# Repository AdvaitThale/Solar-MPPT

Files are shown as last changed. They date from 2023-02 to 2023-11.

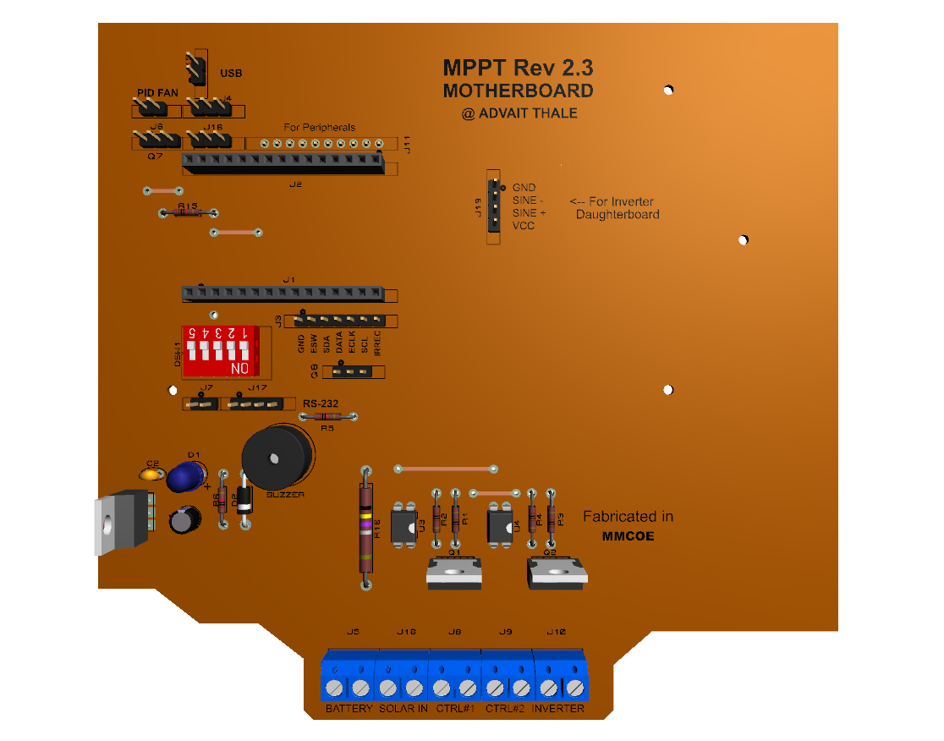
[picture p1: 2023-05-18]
Final Review/Top.PNG

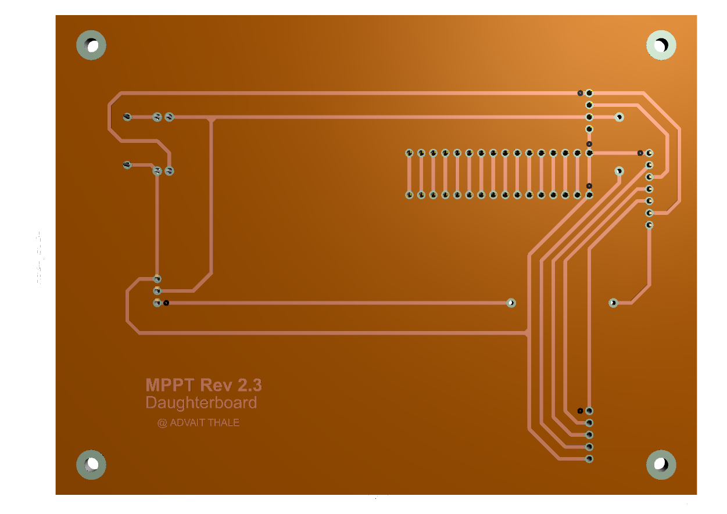
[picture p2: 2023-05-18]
Final Review/Back LCD.PNG

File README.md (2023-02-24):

# Solar-MPPT
***************************************************************
The basic functionality of the device is based on previous generation Solar MPPTs, but it is fully autonomous (alpha ver) using ESP32 as microcontroller.
The file named `MPPT_Port-Xtensa.ino` code is final port of MPPT on the ESP32. Also, `MPPT_Port-328P.ino` shows an overview of how MPPT will work with ATMega328P microcontroller (with reduced functionality).It is equipped with 20*4 Character LCD (for device & energy status), Function Buttons, ESP32 Microcontroller, Solar Inlet, 30A FUSE, Sleep Mode, Webserver, 2 x PT-100(for Indoor & Outdoor Temp.), RS-232 Interface(at 9600),Program Serial(at 115200), Internal DIP Switches (for system configuration), Relay driven Outputs(for automation purpose), I/O for interfacing external sensors and automation purpose. The live status is displayed on LCD, the Webserver(at 192.168.1.1) to freely receive updates on PC/smartphone as well as the data log can be viewed via both RS-232 (DB9) or USB A Serial ports. Refer README.md and attached datasheets for furthur details on MPPT.

 IR Remote Keypad Hex Map:
  
        +------------------+              
        |              DC  |
        |                  |
        |  92    93    CC  |
        |  8E    8F    C8  |
        |  8A    8B    C4  |
        |  CF    87    82  |
        |                  |
        |  80    9C    85  |
        |  81  8C  DD  86  |
        |                  |
        |        CA        |
        |  88 99 CE C1 C5  |
        |        D2        |
        |                  |
        |  DA          D6  |
        |      98  95      |
        |                  |
        |  CD    91    D0  |
        |  8D  97  C3  83  |
        |                  |
        |  89  84  D9  96  |
        |                  |
        |     hathw@y      |
        +------------------+

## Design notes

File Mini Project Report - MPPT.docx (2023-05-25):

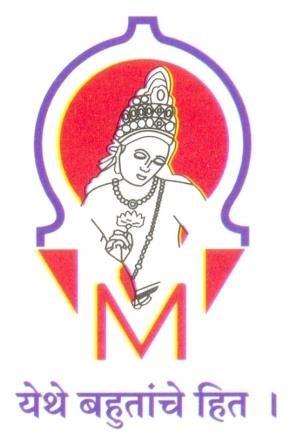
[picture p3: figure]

T.E. MINI PROJECT REPORT

On

“Maximum Power Point Tracker with Controllable Opto-isolated Solid-state outputs and function driven status display”

Submitted by

Advait Thale Exam No:-T190453143

Mansi Veer Exam No:-T190453148

UNDER THE GUIDANCE OF

Prof. Jitendra Bakliwal (Internal Guide)

IN PARTIAL FULFILLMENT OF

T.E. (ELECTRONICS & TELECOMMUNICATION) SAVITRIBAI PHULE PUNE UNIVERSITY

2022-2023

MARATHAWADA MITRA MANDAL’S COLLEGE OF ENGINEERING, PUNE- 52

DEPARTMENT OF ELECTRONICS AND TELECOMMUNICATION

MARATHAWADA MITRA MANDAL’S

COLLEGE OF ENGINEERING, PUNE

CERTIFICATE

This is to certify that the Mini Project Report entitled,

“Maximum Power Point Tracker with Controllable Opto-isolated Solid-state outputs and function driven status display”

Submitted by

Advait Thale Exam No:- T190453143

Mansi Veer Exam No:- T190453148

is Bonafide work carried out by them under the supervision of Prof. Mr. Jitendra Bakliwal and it is approved for the partial fulfilment of requirement of Savitribai Phule Pune University for award of the degree of Bachelor of Engineering (Electronics and Telecommunication).

This project report has not been earlier submitted to any other Institute or University for the award of any degree or diploma.

Mr. Jitendra Bakliwal Dr. G. S. Gawande Dr.V. N. Gohokar

Project Guide Head of Department Principal

Department of E&TC Department of E&TC MMCOE

Place: Pune

Date:

INDEX

Abstract

List of Figures

1. Chapter 1 07
  1.1 Introduction 08
2. Chapter 2 10
  2.1 Literature Survey 11
3. Chapter 3 13
  3.1 System Specifications 14
  3.2 Block Diagram 14
4. Chapter 4 16
  4.1 Hardware Implementation 17
  4.2 System Schematic and Circuit Diagram 19
  4.3 PCB Artwork 20

4.4 3D Render 21

1. Chapter 5 24
  1.1 Practical Implementation 25
2. Chapter 6 27
  2.1 Conclusion… 28
  2.2 Future Scope 28
  2.3 Schedule 26

REFERENCES

LIST OF FIGURES

Sr. No. | Name of Figure | | Page No.
3.1 | Block Diagram | | 14
4.1 | ESP32 Dev Module | | 17
4.2 4.3 | Circuit Diagram PCB Layout of Main Board | | 19 20
4.4 | PCB Layout of LCD Daughterboard | | 20
4.5 | Top View of Main Board | | 21
4.6 | Isometric View of Main Board | | 21
4.7 | Back View of Main Board (Routes) | | 22
4.8 | Front view of LCD Daughterboard (Routes) | | 23
4.9 | Back view of LCD Daughterboard (Routes) | | 23
5.1 | Parameters on LCD | | 25
5.2 | Practical Implementation | | 25
5.3 | Serial Monitor Output | | 26

ABSTRACT

The abstract focuses on controllable Maximum Power Point Tracking (MPPT) techniques designed to further enhance the power output of photovoltaic (PV) systems. As solar energy becomes increasingly prominent, optimizing the performance of PV modules through effective MPPT algorithms has become crucial. This abstract provides a concise overview of controllable MPPT techniques and their potential for maximizing PV power generation.

The aim was to display how much voltage is being generated by photovoltaic panels, current flowing through the batteries or battery bank, temperature of battery bank along with cut-off protection in case of battery overheating, customizable charging, settings menu which will be displayed on character LCD and controlled by KY-040 rotary encoder module and most importantly controlled DC outputs.

ORGANISATION OF REPORT

The project “Maximum Power Point Tracker with Controllable Opto-isolated Solid-state outputs and function driven status display” is thoroughly explained in all the chapters in this report. Planning and organization of this subject has been done with curiosity and as per the given deadline. So, this project gives the entire overview of this subject.

The report is divided into various chapters to understand each aspect of the subject technically and separately.

Chapter 1:

Gives a brief introduction of this project. This consists of the introduction and scope of the project, objective of this project.

Chapter 2:

Gives brief review of the related Literature and present scenario of proposed system.

Chapter 3:

Describes System Schematic & Specification and block diagram with its detailed explanation.

Chapter 4:

Describes the implementation of the project with its hardware and software description that is detailed analysis of each component.

Chapter 5:

Describes the implementation of small modules and algorithms used in projects. Shows the results and observations.

Chapter 6:

Describes Semester wise planning and management.

CHAPTER 1

INTRODUCTION

1.1 INTRODUCTION:

The integration of maximum power print tracking (MPPT) techniques with controllable opto-isolated solid-state outputs presents a promising solution for enhancing the efficiency and performance of power conversion systems and also represents a compelling research area that holds significant potential for enhancing the efficiency, reliability and safety of power conversion systems in various applications. This project aims to explore the advancements in this area and provide an overview of the current state of the art research and aims to explore the synergistic effects of combining MPPT algorithms, quasi-resonant topologies, and hardware-controlled opto-isolated AC outputs, with a particular focus on their impact on system performance and functionality.

MPPT algorithms plays a crucial role in photovoltaic (PV) systems by dynamically adjusting the operating point of solar panels to extract the maximum power under varying environmental conditions. The integration of MPPT techniques with quasi-resonant topologies offers an opportunity to mitigate switching losses and optimize power transfer, thereby improving the overall efficiency of power conversion systems. Quasi-resonant topologies, characterized by resonant components operating near their natural frequencies, facilitate soft switching and reduce stress on power devices, contributing to enhanced performance and reduced power losses.

Furthermore, a function-driven status display adds value by providing real-time feedback on system performance, fault detection, and diagnostic information. The display acts as a user-friendly interface, allowing operators to monitor the system's operation, identify potential issues, and perform necessary maintenance promptly. This feature facilitates efficient system management, improves reliability, and streamlines troubleshooting processes. This project aims to delve deeply into the theoretical and practical aspects of integrating MPPT techniques, quasi-resonant topologies, and hardware-controlled opto-isolated AC outputs. Through experimental investigations and analysis, the project will evaluate the performance metrics, such as power efficiency, response time, and power quality, to assess the advantages and challenges of this integrated approach. Furthermore, the project will explore control strategies, optimization techniques, and design considerations to maximize the benefits of this integrated system.

The outcomes of this project will contribute to the existing body of knowledge in the field of power electronics, renewable energy, and system integration. The findings will shed light on the feasibility, advantages, and potential applications of combining MPPT techniques, quasi-resonant topologies, and hardware-controlled opto-isolated AC outputs. This knowledge will provide valuable insights for researchers, engineers, and practitioners seeking to optimize power conversion systems, improve renewable energy utilization, and enhance the safety and reliability of electrical systems.

CHAPTER 2

LITERATURE SURVEY

2.1 LITERATURE SURVEY:

As part of pre-study, an elaborate literature survey was conducted. The literature survey presents an overview on the Maximum Power Point Tracker, Controllable Opto-isolated Solid-state outputs, and function scrolling on LCD. The journals were analysed, and content was presented. After analysing what systems have been published in the journals, ideas which were presented focused on improving the existing system and trying to implement a cost-efficient alternative to existing MPPTs [4].

After thoroughly classifying every MPPTs available in the market offline as well as online, there exists no display to properly check how much voltage is being generated by photovoltaic panels, current flowing through the batteries or battery bank, temperature of battery bank along with cut-off protection in case of battery overheating [4], customizable charging, and most importantly controlled DC outputs.

With the help of newly designed IoT based microcontrollers [6], the goal of adding above requirements atop of normal MPPT operation improving visibility of work being done were achieved. It has emerged as a useful industrial tool for about 25 years and is growing at a higher speed. The applications of newly designed microcontrollers in industries as well as in commercial areas have been typically seen in wireless monitoring, wireless load controlling, various types of automation systems including domestic version as home automation system, remote quality control, remote object sorting, and remote robotic operation and guidance. It has become a yielding tool in product inspection and analysis because it reduces cost, effort, and time with a significant level of accuracy and reliability. With the recent advancement in technology, IoT based microcontrollers can be applied to remotely control as well as monitor various environmental parameters and to collect data from different sensors connected, etc. The application of IoT based microcontrollers has been seen in domestic, medical, industrial, security fields, and in remote monitoring.

The ESP32 microcontroller for controlling and monitoring all the ongoing operations was used [8]. Also, C, C++ programming languages were the preferred choices as the whole ESP program environment is built on them and they are the most efficient programming languages till date for writing libraries and to efficiently compile the program. ESP32 is low cost, SoC single board 32-bit microcontroller with built-in 2.4 GHz Wi-Fi Radio, Bluetooth 4.2 and Bluetooth Low Energy [7]. It can be used to store and display web pages on the PC or smartphone in the browser and the data from the sensors can be viewed in real time. A 16x2 character LCD placed atop the enclosure is used to display the voltage, current and temperature parameters of the battery and produced voltage from PV panels [1] [4].

CHAPTER 3

SYSTEM SCHEMATIC &

SPECIFICATION

3.1 SPECIFICATIONS:

1. 12-24V Photovoltaic Panel Input
2. MOSFET Controlled Output x 2
3. Outputs Controlled by IR Remote
4. Character LCD for Power Status
5. Webserver Access at 192.168.1.1
6. 12V Lead Acid Battery (4V 1AH x 3 in series)
7. Overtemperature Battery Cut-off Protection
8. Port for KY-040 Rotary Encoder for Settings Menu
9. System Alarms through integrated beeper

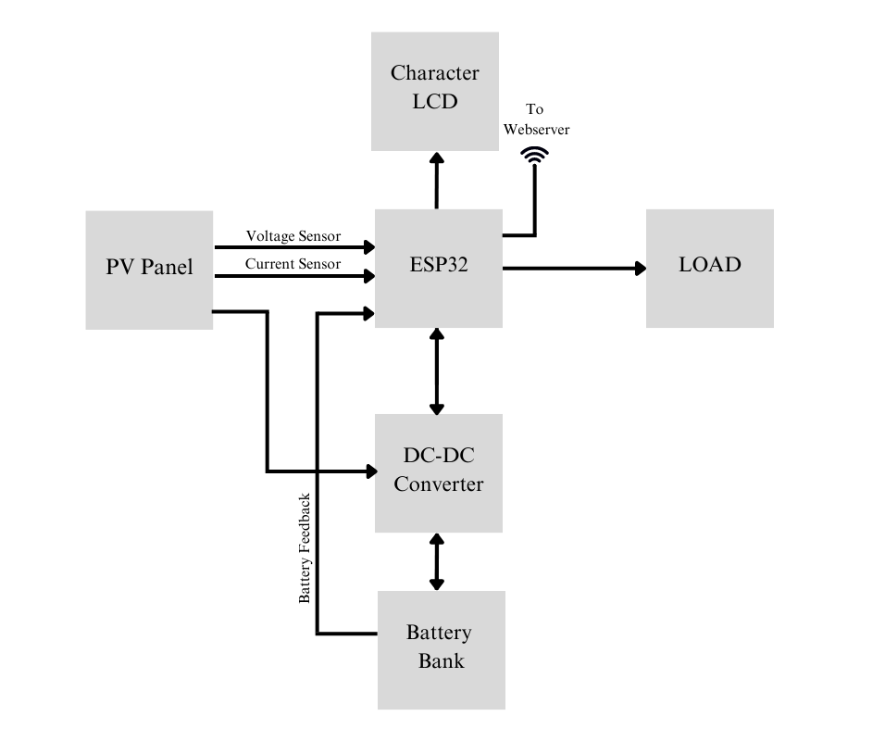
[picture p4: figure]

3.2 BLOCK DIAGRAM:

Fig. 3.1: Block Diagram of ESP32 Based MPPT with Status LCD

WORKING:

The ESP32 is used to control all the important tasks for charging/ using battery bank, to monitor the voltage and current of battery and power generated by PV Panels. The obtained data can be viewed on the character LCD atop of the MPPT enclosure as well as on the webserver in real time. With the help of connected current sensor and ADC, it constantly checks how much voltage is being generated by photovoltaic panels, current flowing through the batteries or battery bank, temperature of battery bank along with cut-off protection in case of battery overheating. The two MOSFET controlled outputs can be used for connecting DC load of 12V Max. The outputs are normally controlled by microcontroller at normal MPPT operations but can be manually controlled by IR remote. If the battery is overheated or is fully charged in those intervals various alerts occur. A header port for KY040 rotary encoder is kept for controlling the output load voltage and battery charge parameters. Also, a header for inverter is routed on the PCB for Inverter daughterboard for further expansion.

CHAPTER 4

CIRCUIT DESIGN &

PCB ARTWORK

4.1 HARWARE USED:

- ESP32:

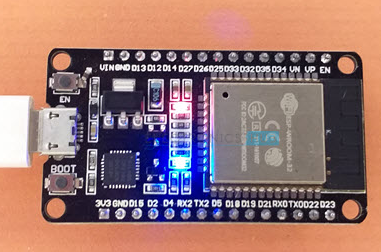
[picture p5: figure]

Fig. 4.1: ESP32 Dev Module

An ESP32 is a popular and versatile microcontroller and Wi-Fi/Bluetooth module that is widely used for IOT applications. The ESP32 is powered by a dual core Tensilica Xtensa LX6 microprocessor. Each core operates at a clock frequency of up to 240 MHz. The ESP32 has a significant number of GPIO pins available for connecting external components and sensors. It typically comes with 4MB to 16MB of built-in flash memory for storing firmware and programs. The power consumption of the ESP32 can vary depending on the usage and operating conditions [7]. It offers low-power modes and features to optimize energy efficiency.

- LM7805:

The LM7805 is a popular linear voltage regulator IC that provides a fixed output voltage of +5 V. It is widely used in electronic circuits to regulate and provide a stable +5V power supply. The LM7805 requires an input voltage higher than the desired output voltage [3]. It typically operates within a range of 7V to 35V. The LM7805 provides a fixed output voltage of +5V. The dropout voltage is the minimum voltage required between the input and output terminals for the LM7805 to regulate the output voltage properly.

- 116*2 Character LCD:

A 16*2 LCD (Liquid Crystal Display) is a commonly used alphanumeric display module that can display 16 characters in each of its rows. It is widely used in various electronic projects and devices for displaying information. The 16*2 LCD module is usually based on an HD44789 or compatible controller. This controller handles the interfacing between the microcontroller and the LCD module, providing commands and data for display control. The 16*2 LCD module is usually interfaced with a backlight pin. The most common interface is the 4-bit or 8-bit parallel interface, where data and control signals are sent to the LCD using multiple data lines.

- 4V Lead Acid Battery:

A 4V lead-acid battery is a type of rechargeable battery commonly used in various applications, including automotive, solar power systems, uninterruptible power supplies (UPS) and other backup power applications. The 4V lead-acid battery is based on a lead-acid chemistry, which consists of lead plates and an electrolyte solution of sulfuric acid (H2SO4). The recommended operating temperature range for lead-acid batteries is typically between -20 °C to 50 °C. Extreme temperatures outside this range can affect the battery’s performance and overall lifespan [2].

- 2N2222A:

The 2N2222A is a popular NPN bipolar junctions’ transistor (BJT) commonly used in a wide range of electronic circuits for switching and amplification purposes. The 2N2222A is an NPN (Negative-Positive-Negative) bipolar junction transistor, which means it consists of three layers of semiconductor material: the emitter(N) , base (P) and collector (N). It is designed to control current flow between the collector and emitter terminals using a voltage applied to the base terminal.

- IRFZ44:

The IRFZ44 is a popular power MOSFET (Metal-Oxide-Semiconductor Field-Effect Transistor) used for high-power switching applications. It is commonly employed in a variety of electronic circuits, such as motor control, LED lighting, and power supplies. The IRFZ44 is an N-channel MOSFET, meaning it is designed to control the flow of current between the drain and source terminals using a voltage applied to the gate terminal. The IRFZ44 is commonly available in a TO-220 package, which allows for easy mounting and heat dissipation.

- IR Receiver (VS1838B):

An IR (Infrared receiver) is a component used to detect and receive infrared signals from remote controls, IR transmitters or other IR sources. It is commonly used in applications such as remote-control systems, home automation and infrared communication. IR receivers typically use a photodiode or phototransistor as the detecting element. These components are sensitive to infrared signals within a specific wavelength range.

4.2 System Schematic and Circuit Diagram:

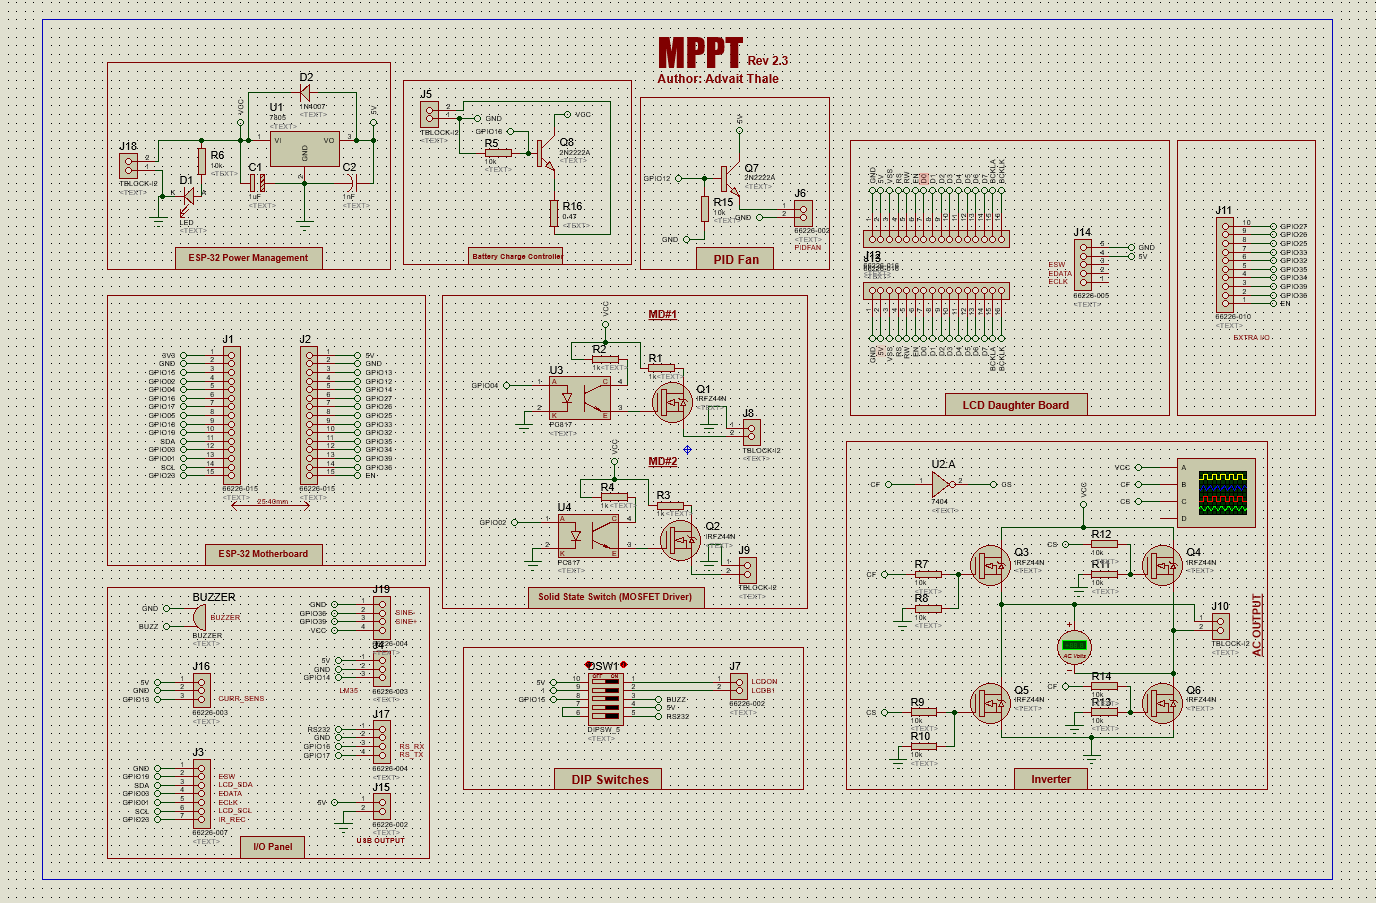
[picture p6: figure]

Fig. 4.2: Circuit Diagram

4.3 PCB Artwork:

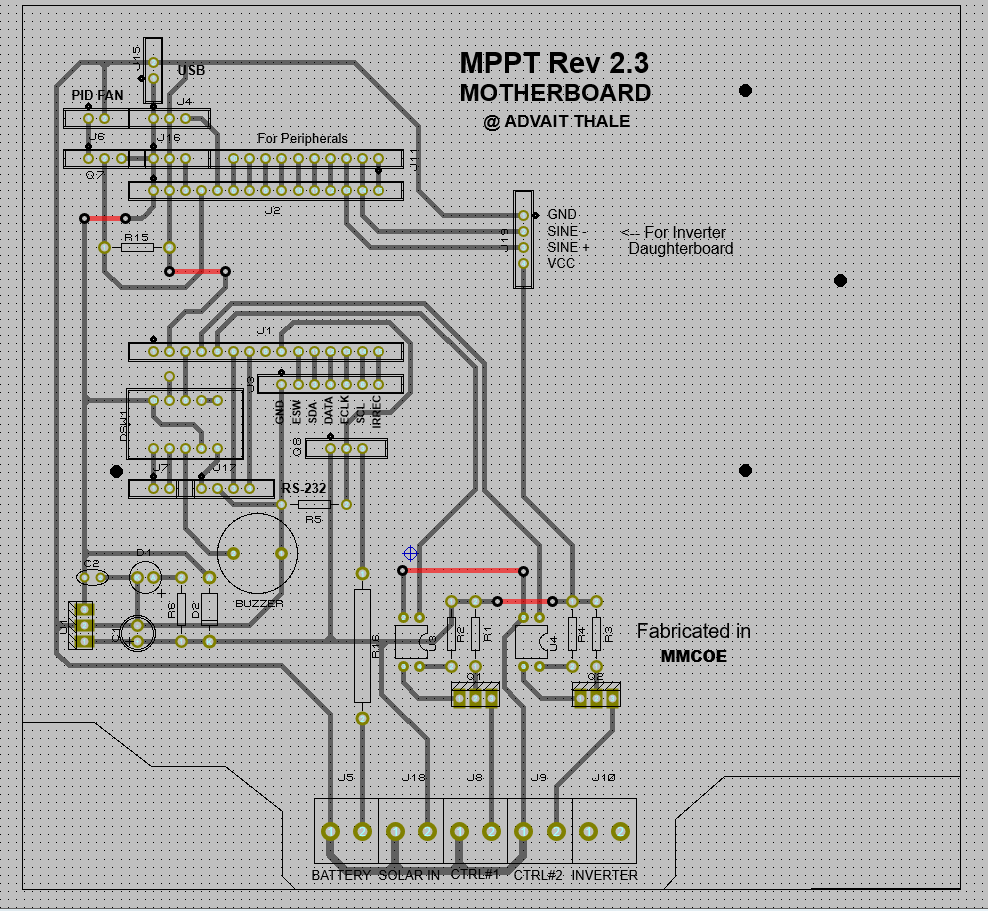
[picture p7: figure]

Fig. 4.3: PCB Layout of Main Board

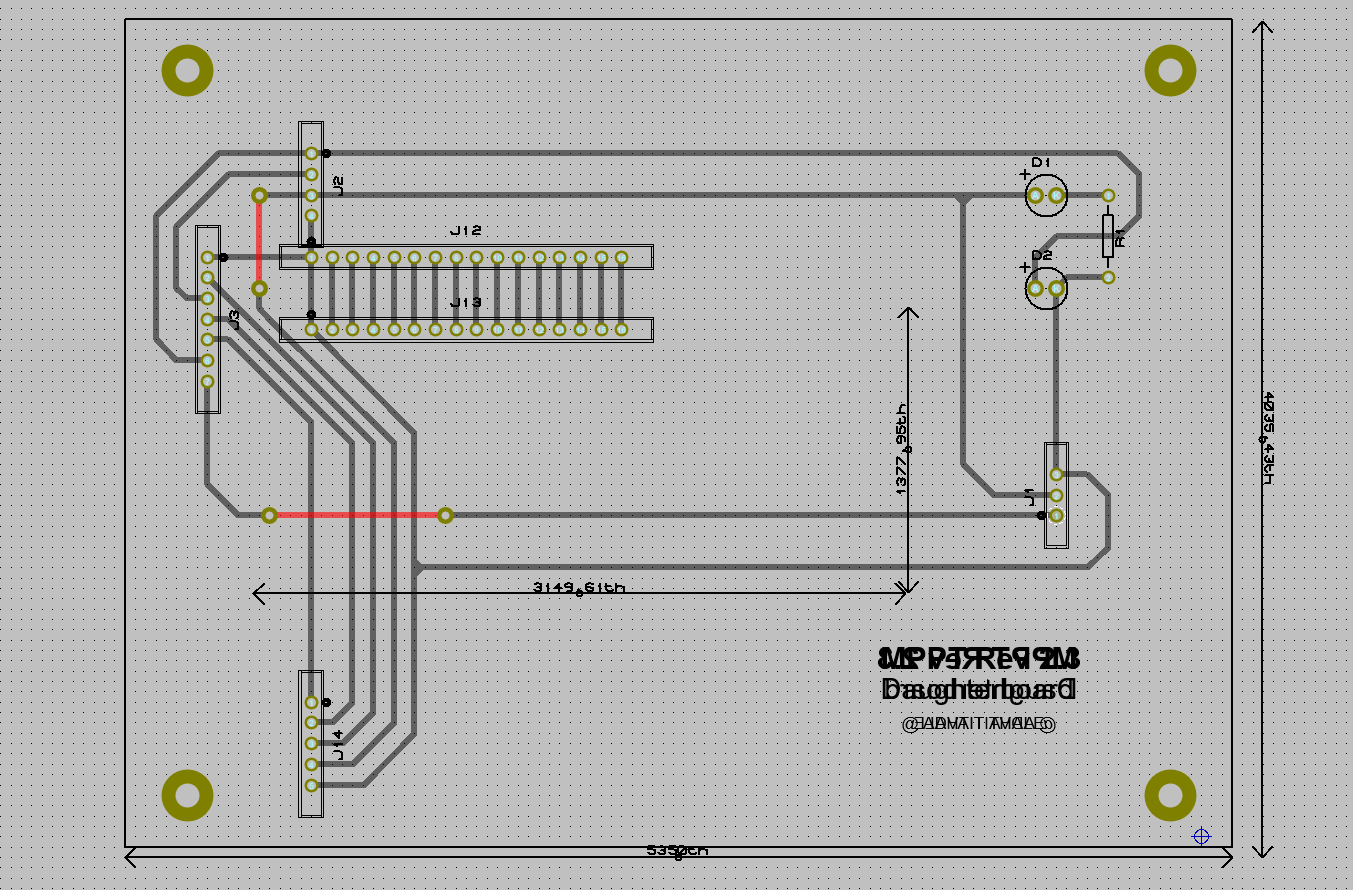
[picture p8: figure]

Fig. 4.4: PCB Layout of LCD Daughterboard

4.4 3D Render of PCB:


Fig. 4.5: Top View of Main Board

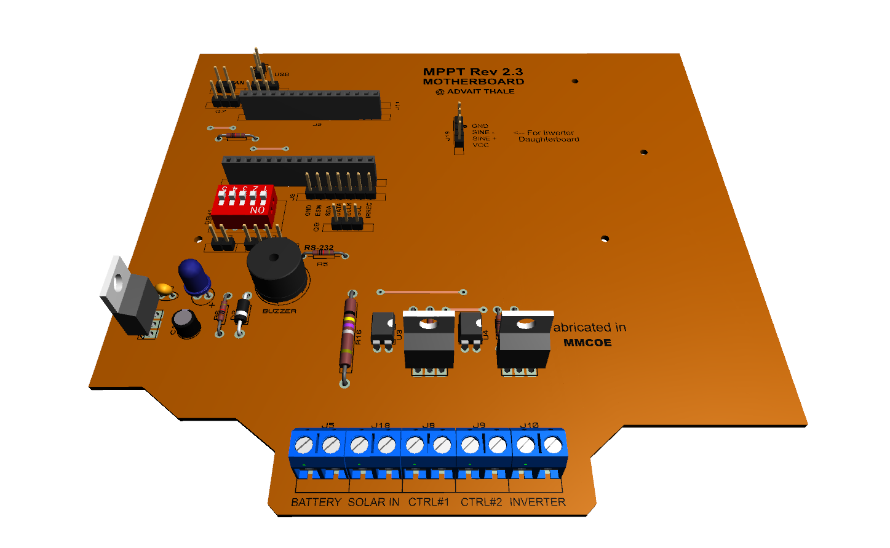
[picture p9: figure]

Fig. 4.6: Isometric view of Main Board

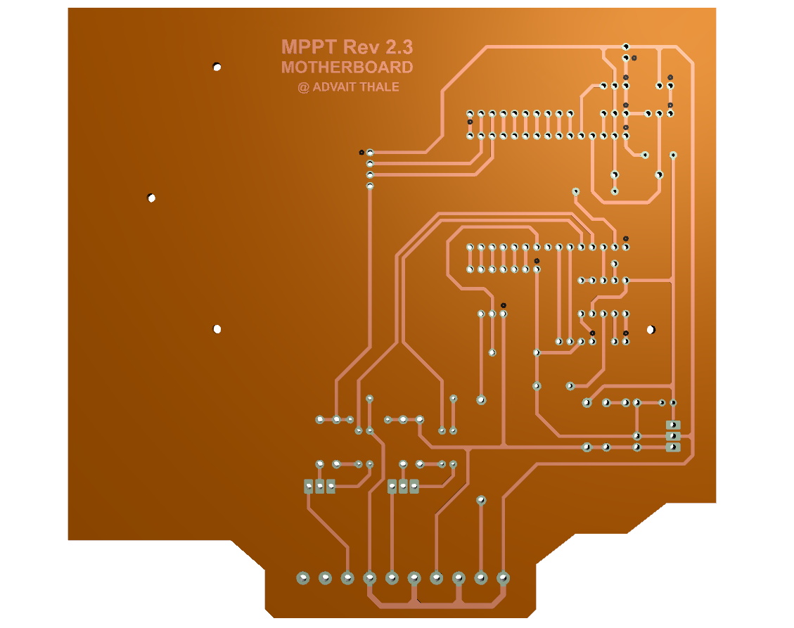
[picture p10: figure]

Fig. 4.7: Back view of Main Board (Routes)

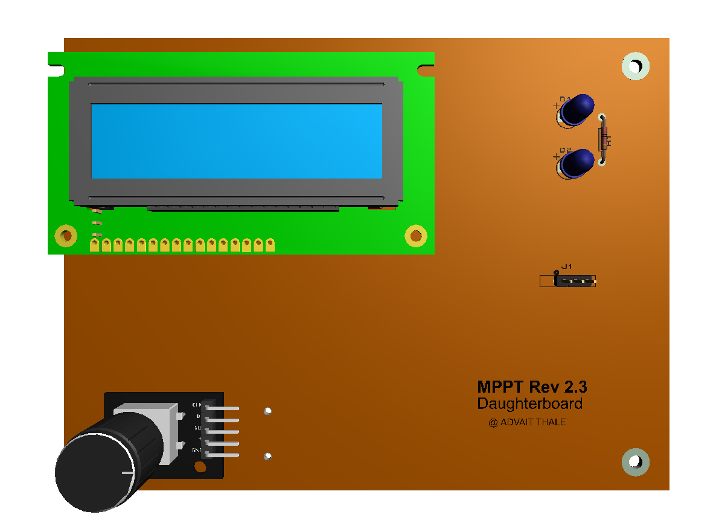
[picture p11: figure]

Fig. 4.8: Front view of LCD Daughterboard (Routes)


Fig. 4.9: Back view of LCD Daughterboard (Routes)

CHAPTER 5

HARDWARE IMPLEMENTATION

5.1 HARDWARE IMPLEMENTATION:

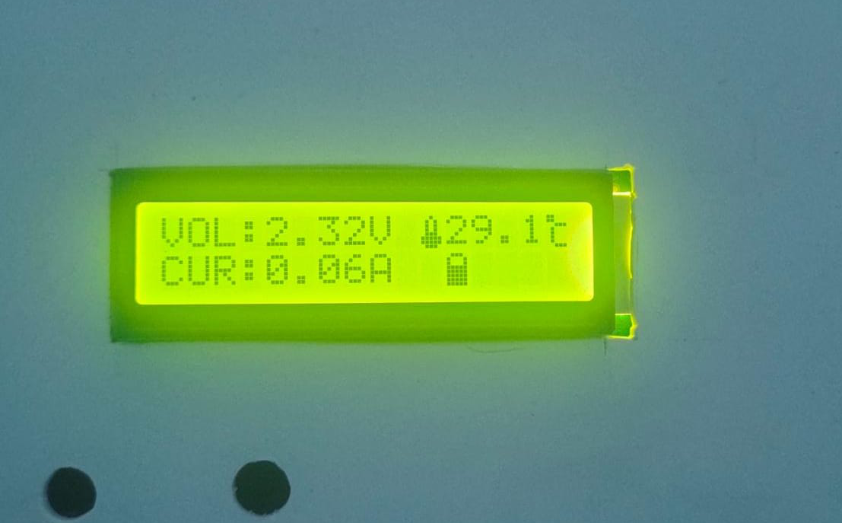
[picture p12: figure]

Fig. 5.1: Parameters on LCD

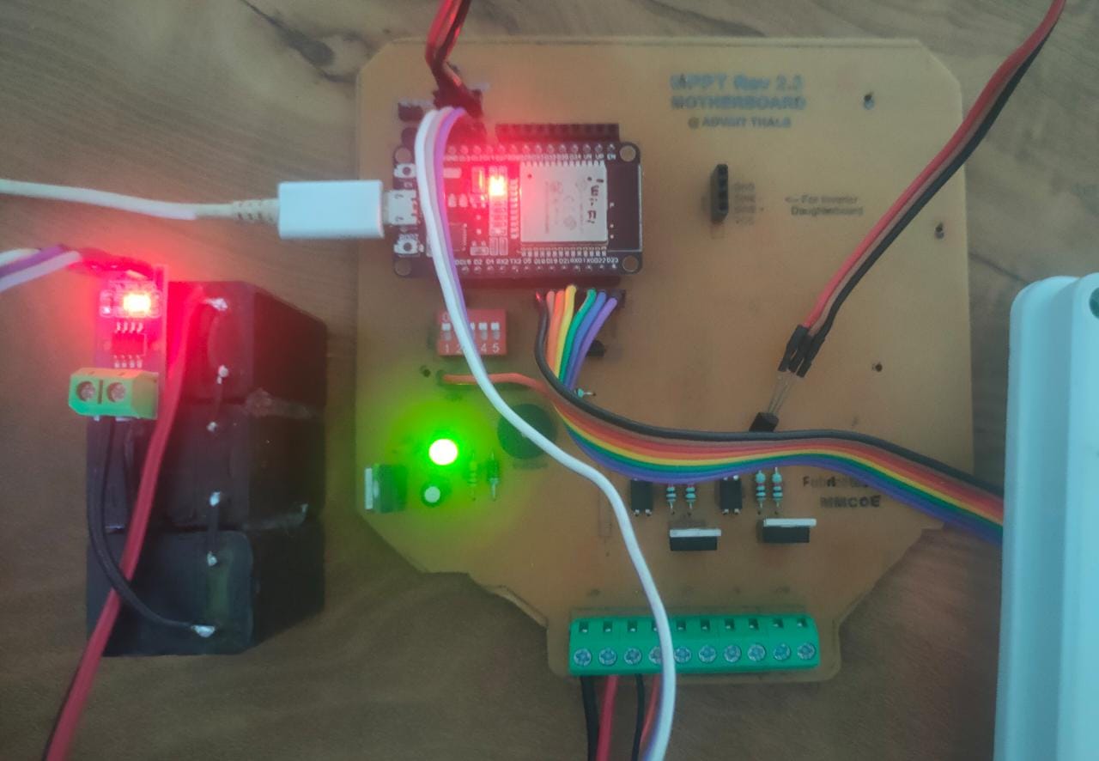
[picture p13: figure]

Fig. 5.2: Practical Implementation

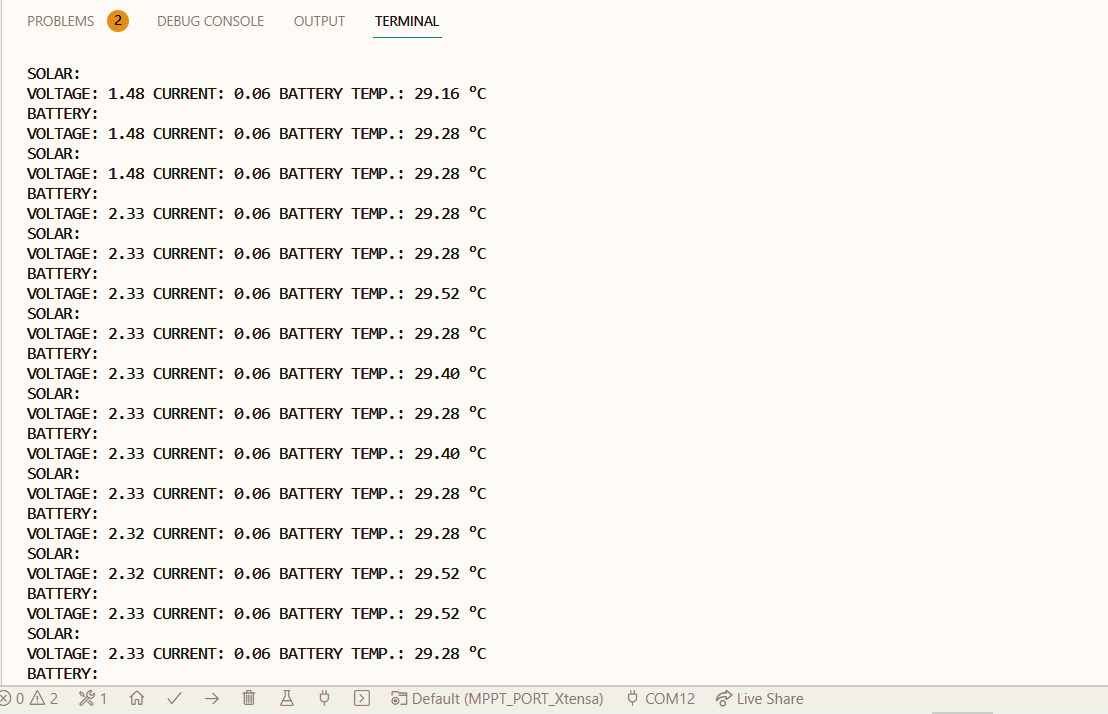
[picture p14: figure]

Fig. 5.3: Serial Monitor Output

CHAPTER 6

PROJECT PLANNING &

METHODOLOGY

6.1 CONCLUSION:

Thus, a working prototype of Output controllable MPPT with Webserver was demonstrated. It shows the Battery charging parameters such as voltage, current across and input power parameters on the character LCD as well as can be viewed on the Webserver by connecting to ESP32 via Wi-Fi and browsing 192.168.1.1 address on the internet browser such as Chrome, Edge, etc. The goal was to try and improve productivity and efficiency of already available device in the market and concluded that it is doable. The data obtained provides high accuracy, good repeatability and increases productivity.

6.2 FUTURE SCOPE:

Future work that can be implemented in this project is, an inverter daughterboard to produce AC output directly from the MPPT with provided connector on PCB can be attached, thereby increasing productivity of device. It can be upgraded to work on higher voltages by simply changing software and hardware components and parameters, respectively. It can be implemented in domestic as well as commercial areas with few advancements better meet overall power demands.

6.3 SCHEDULE:

Week 1 (28-01-23): Group formation and problem statement search.

Week 2 (03-02-23): Project topic finalization.

Week 3 (10-02-23): Problem solving and circuit designing.

Week 4 (17-02-23): Component availability check according to circuits.

Week 5 (24-02-23): Finalizing circuit diagram with available components.

Week 6 (03-03-23): PCB Designing.

Week 7 (10-03-23): Purchased Enclosure and adjusted PCB size.

Week 8 (17-03-23): Finalizing PCB Artwork.

Week 9 (24-03-24): Manufacturing PCB.

Week 10 (31-03-23): Assembling components on PCB and Testing.

Week 11 (08-04-23): Optimizing code and LCD Daughterboard design.

Week 12 (13-04-23): Code correction and testing.

Week 13 (21-04-23): Final PCB fitting in enclosure and project review.

Week 14 (28-04-23): Project Presentation.

REFERENCES:

[1] Paul Horowitz, Winfield Hill, “Solar Cells”, in The Art of Electronics, Second Edition, Pg. 932-933.

[2] W. H. Hayt, J. E. Kemmerly, S. M. Durbin, “Ohm’s Law: Power Absorption”, in Engineering Circuit Analysis, Seventh Edition, Pg. 21-27

[3] Paul Horowitz, Winfield Hill, “Voltage, Current & Resistance”, in The Art of Electronics, Second Edition, Pg. 2-9.

[4] D. P. Kothari, I.J. Nagrath, “Solar Energy & its Utilisation”, in Modern Power System Analysis, Fourth Edition, Pg. 32-42

[5] Paul Horowitz, Winfield Hill, “Power Sources: Battery Types”, in The Art of Electronics, Second Edition, Pg. 920-931.

[6] Clint Smith, Daniel Collins, “Long Term Evolution: RF Coverage Analysis”, in Wireless Networks, Third Edition, Pg. 497-50

[7] Louis E. Frenzel, “Radio Frequency Wave Propagation”, in Communication Electronics, Third Edition, Pg. 247-251

[8] Clint Smith, Daniel Collins, “Long Term Evolution: Radio Spectrum”, in Wireless Networks, Third Edition, Pg. 211-213

[9] Paul Horowitz, Winfield Hill, “Measurement Transducers: Temperature”, in The Art of Electronics, Second Edition, Pg. 988-996.

MMCOE - B. E. ELECTRONICS AND TELECOMMUNICATION

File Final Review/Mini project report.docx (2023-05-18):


T.E. MINI PROJECT REPORT

## On

“Maximum Power Point Tracker with Controllable Opto-isolated Solid state outputs and function driven status display”

Submitted by,

Advait Thale (T190453143) Mansi Veer (T190453148)

UNDER THE GUIDANCE OF

Prof. Jitendra Bakliwal (Internal Guide)

IN PARTIAL FULFILLMENT OF

T.E. (ELECTRONICS & TELECOMMUNICATION) SAVITRIBAI PHULE PUNE UNIVERSITY

2021-2022

MARATHAWADA MITRA MANDAL’S COLLEGE OF ENGINEERING, PUNE- 52

DEPARTMENT OF ELECTRONICS AND TELECOMMUNICATION

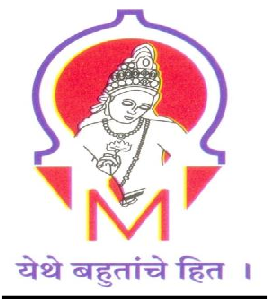
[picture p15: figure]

MARATHAWADA MITRA MANDAL’S

COLLEGE OF ENGINEERING, PUNE

CERTIFICATE

This is to certify that the Mini Project report entitled

“Maximum Power Point Tracker with Controllable Opto-isolated Solid state outputs and function driven status display”

Submitted by

Advait Thale Exam No:-T190453143

Mansi Veer Exam No:-T190453148

is bonafide work carried out by them under the supervision of Prof Mr.Jitendra Bakliwal and it is approved for the partial fulfillment of requirement of Savitribai Phule Pune University for award of the degree of Bachelor of Engineering (Electronics and Telecommunication).

This seminar report has not been earlier submitted to any other Institute or University for the award of any degree or diploma.

Dr. Jitendra Bakliwal

Project Guide

Department of E&TC

Dr. G. S. Gawande

Head of Department Department of E&TC

Dr. V. N. Gohokar Principal

Place: Pune Date:

## INDEX

1. Chapter1 06
  1.1 Introduction 07
2. Chapter 2 09
  2.1 Literature Survey 10
3. Chapter3… 11
  3.1 System schematic and specification 12
  3.2 Block diagram 13
4. Chapter 4 14
  4.1 Hardware Implementation with PCB Artwork 15
  4.2 3D Render… 17
5. Chapter 5 18
  5.1 algorithm 19
  5.2 Implementation of sorting mechanism 20
  5.3 21
6. Chapter 6 24
  6.1 Conclusion… 25
  6.2 Future Scope 25

## LIST OF FIGURES

Sr. No. | Name of Figure | Page No.
3.1 | Block Diagram
4.1 | Raspberry-pi module
4.2 | Schematic Screenshot of PCB Routes
5.1 | Flow Chart
5.2 | Controller
5.3 | Screenshot of Program and Serial Monitor
5.4 | Practical Working Image
5.5 | Commands required for capturing an image
5.6(a) | Top view of PCB (3D)
5.6(b) | Isometric view of PCB (3D)
5.6(c) | Back view of PCB (Routes) (3D)

# ABSTRACT

# ORGANISATION OF REPORT

Our project “Maximum Power Point Tracker with Controllable Opto-isolated Solid state outputs and function driven status display” is thoroughly explained in all the chapters in this report . Planning and organization of this subject has been done with curiosity and as per the given deadline. So this project gives the entire overview of this subject.

The report is divided into various chapters to understand each aspect of the subject technically and separately.

## Chapter 1:

## Gives a brief introduction of this project. This consists of the introduction and scope of the project, objective of this project.

## Chapter 2:

## Gives brief review of the related Literature and present scenario of proposed system.

## Chapter 3:

## Describes System Schematic & Specification and block diagram with its detailed explanation.

## Chapter 4:

## Describes the implementation of the project with its hardware and software description that is detailed analysis of each component.

## Chapter 5:

## Describes the implementation of small modules and algorithms used in projects. Shows the results and observations.

## Chapter 6:

## Describes Semester wise planning and management.

# CHAPTER 1 INTRODUCTION

## 1.1 INTRODUCTION

The integration of maximum power print tracking (MPPT) techniques with controllable opto-isolated solid state outputs presents a promising solution for enhancing the efficiency and performance of power conversion systems and also represents a compelling research area that holds significant potential for enhancing the efficiency , reliability and safety of power conversion systems in various applications. This project aims to explore the advancements in this area and provide an overview of the current state of the art research and also aims to explore the synergistic effects of combining MPPT algorithms, quasi-resonant topologies and hardware-controlled opto-isolated AC outputs,with a particular focus on their impact on system performance and functionality.

MPPT algorithms plays a crucial role in photovoltaic (PV) systems by dynamically adjusting the operating point of solar panels to extract the maximum power under varying environmental conditions.The integration of MPPT techniques with quasi-resonant topologies offers an opportunity to mitigate switching losses and optimize power transfer, thereby improving the overall efficiency of power conversion systems. Quasi-resonant topologies, characterized by resonant components operating near their natural frequencies, facilitate soft switching and reduce stress on power devices, contributing to enhanced performance and reduced power losses.

Furthermore, a function-driven status display adds value by providing real-time feedback on system performance, fault detection, and diagnostic information. The display acts as a user-friendly interface, allowing operators to monitor the system's operation, identify potential issues, and perform necessary maintenance promptly. This feature facilitates efficient system management, improves reliability, and streamlines troubleshooting processes.This project aims to delve deeply into the theoretical and practical aspects of integrating MPPT techniques, quasi-resonant topologies, and hardware-controlled opto-isolated AC outputs. Through experimental investigations and analysis, the project will

evaluate the performance metrics, such as power efficiency, response time, and power quality, to assess the advantages and challenges of this integrated approach. Furthermore, the project will explore control strategies, optimization techniques, and design considerations to maximize the benefits of this integrated system.

The outcomes of this project will contribute to the existing body of knowledge in the field of power electronics, renewable energy, and system integration. The findings will shed light on the feasibility, advantages, and potential applications of combining MPPT techniques, quasi-resonant topologies, and hardware-controlled opto-isolated AC outputs. This knowledge will provide valuable insights for researchers, engineers, and practitioners seeking to optimize power conversion systems, improve renewable energy utilization, and enhance the safety and reliability of electrical systems.

## 2.1 LITERATURE SURVEY

As part of our pre-study, we conducted an elaborate literature survey. The literature survey presents an overview on the Maximum Power Point Tracker, Controllable Opto-isolated Solid state outputs, and function scrolling on LCD. The journals were analyzed and content was presented. After analyzing what systems have been published in the journals, we presented our ideas which were focussed on improving the existing system and trying to implement a cost efficient alternative to existing MPPTs.

After thoroughly classifying every MPPTs available in the market offline as well as online, we came to realize that, there exist no display to properly check how much voltage is being generated by photovoltaic panels, current flowing through the batteries or battery bank, temperature of battery bank along with cutoff protection in case of battery overheating, customizable charging and most importantly controlled DC outputs.

With the help of newly designed IoT based microcontrollers we can achieve the goal of adding above requirements atop of normal MPPT operation improving visibility of work being done. It has emerged as a useful industrial tool for about 25 years and is growing at a higher speed. The applications of newly designed microcontrollers in industries as well as in commercial areas have been typically seen in wireless monitoring, wireless load controlling, various types of automation systems including domestic version as home automation system, remote quality control, remote object sorting, and remote robotic operation and guidance. It has become a yielding tool in product inspection and analysis, because it reduces cost, effort, and time with a significant level of accuracy and reliability. With the recent advancement in technology, IoT based microcontrollers can be applied to remotely control as well as monitor various environmental parameters and to collect data from different sensors connected, etc. The application of IoT based microcontrollers has been seen in domestic, medical, industrial, security fields, and in remote monitoring.

We used ESP32 microcontroller for controlling and monitoring all the ongoing operations. We used C, C++ programming languages as the whole ESP program environment is built on them and they are the most efficient programming languages till date for writing libraries and to efficiently compile the program. ESP32 is low cost, SoC single board 32-bit microcontroller with built-in 2.4 GHz WiFi Radio, Bluetooth 4.2 and Bluetooth Low Energy. It can be used to store and display web pages on the PC or smartphone in the browser and the data from the sensors can be viewed in real time. A 16x2 character LCD placed atop the enclosure is used to display the voltage, current and temperature parameters of the battery and produced voltage from PV panels.

settings menu on the display voltage control.

# CHAPTER 3

SYSTEM SCHEMATIC AND SPECIFICATION

## 3.1 SPECIFICATION

## 3.2 BLOCK DIAGRAM

SOAR POWER

CONTROLLER

CONVEYOR AND SENSORS

RASPBERRYPI

CAMERA

DISPLAY

Fig 3.1 Block Diagram

DETAILED EXPLANATION:

The detailed block diagram of proposed system is shown in fig above.

    - The Camera is used for image acquisition.
    - Image acquired is given to RaspberryPi and OpenCV is used as an image processing platform. The OpenCV code written in Python is trained to examine the parameters like Shape, Colour and Texture for identification of products.
    - The RaspberryPi will generate the corresponding signals according to the image data interpreted by OpenCV. These signals are then given to the Controller which further handles the Sorting mechanism.
    - The controller will also perform the operation of counting the number of products and displaying the appropriate count on LCD.

# CHAPTER 4

SYSTEM DESIGN HARDWARE

AND SOFTWARE

## 4.1 HARDWARE IMPLEMENTATION AND PCB LAYOUT

- ESP32:

An ESP32 is a popular and versatile microcontroller and Wi-Fi/Bluetooth module that is wisely used for IOT applications. The ESP32 is powered by a dual+core Tensilica Xtensa LX6 microprocessor. Each core operates at a clock frequency of up to 240 MHz.The ESP32 has a significant number of GPIO pins available for connecting external components and sensors.It typically comes with 4MB to 16MB of built-in flash memory for storing firmware and programs.

The power consumption of the ESP32 can vary depending on the usage and operating conditions. It offers low-power modes and features to optimize energy efficiency.

- LM7805:

The LM7805 is a popular linear voltage regulator IC that provides a fixed output voltage of +5 V. It is widely used in electronic circuits to regulate and provide a stable +5V power supply. The LM7805 requires an input voltage higher than the desired output voltage. It typically operates within a range of 7V to 35V. The LM7805 provides a fixed output voltage of +5V. The dropout voltage is the minimum voltage required between the input and output terminals for the LM7805 to regulate the output voltage properly.

- 116*2 LCD:

A 16*2 LCD (Liquid Crystal Display) is a commonly used alphanumeric display module that can display 16 characters in each of its rows. It is widely used in various electronic projects and devices for displaying information. The 16*2 LCD module is usually based on an HD44789 or compatible controller. This controller handles the interfacing between the microcontroller and the LCD module , providing commands and data for display control. The 16*2 LCD module is usually interfaced with a backlight pin. The most common interface is the 4-bit or 8-bit parallel interface, where data and control signals are sent to the LCD using multiple data lines.

- 4V Lead Acid Battery:

A 4V lead-acid battery is a type of rechargeable battery commonly used in various applications, including automotive, solar power systems, uninterruptible power supplies (UPS) and other backup power applications. The 4V lead-acid battery is based on a lead-acid chemistry, which consists of lead plates and an electrolyte solution of sulfuric acid (H2SO4).The recommended operating temperature range for lead-acid batteries is typically between -20 degC to 50 degC. Extreme temperatures outside this range can affect the battery’s performance and overall lifespan.

- 2N2222A:

The 2N2222A is a popular NPN bipolar junctions transistor(BJT) commonly used in a wide range of electronic circuits for switching and amplification purposes.The 2N2222A is an NPN (Negative-Positive-Negative) bipolar junction transistor, which means it consists of three layers of semiconductor material:the emitter(N) , base (P) and collector (N). It is designed to control current flow between the collector and emitter terminals using a voltage applied to the base terminal.

- IRFZ44:

The IRFZ44 is a popular power MOSFET (Metal-Oxide-Semiconductor Field-Effect Transistor) used for high-power switching applications. It is commonly employed in a variety of electronic circuits, such as motor control, LED lighting, and power supplies. The IRFZ44 is an N-channel MOSFET, meaning it is designed to control the flow of current between the drain and source terminals using a voltage applied to the gate terminal. The IRFZ44 is commonly available in a TO-220 package, which allows for easy mounting and heat dissipation.

## IR Receiver:

An IR (Infrared receiver) is a component used to detect and receive infrared signals from remote controls , IR transmitters or other IR sources. It is commonly used in applications such as remote control systems , home automation and infrared communication. IR receivers typically use a photodiode or phototransistor as the detecting element. These components are sensitive to infrared signals within a specific wavelength range.

## 4.2 ENCLOSURE DESIGN

Fig 4.2 Catia Design

This is the mechanical design of the project. It shows the design of connected conveyor, mounting of camera and sensors.

# CHAPTER 5

# ALGORITHMS AND TEST RESULTS

## 5.1 IMAGE PROCESSING AND SORTING ALGORITHM

START

TURN ON IMAGE ACQUISATION DEVICE TO CAPTURE IMAGE OF PRODUCT

IS DATA RECEIVED?

WAIT FOR DATA RECEPTION IN OpenCV

DETERMINE SHAPE, TEXTURE, COLOUR

OBJECT A

OBJECT B

OBJECT C

M1-CLOCKWISE

M2- ANTICLOCKWISE

M1- CLOCKWISE

M2- CLOCKWISE

M1- ANTICLOCKWISE

M2-OFF

Fig 5.1 Flow chart

## 5.2 IMPLEMENTATION OF SORTING MECHANISM

Fig 5.2 Controller and motors

Fig 5.3 Screenshot of Program and Terminal

Figure shows hardware and software implementation used for sorting mechanism. RaspberryPi will give signals to Controller , further controller will control the motors which drives the conveyors.

## 5.3 WEBCAM INTERFACING WITH RaspberryPi

Fig 5.4 Image taken by the webcam

# CHAPTER 6

# PROJECT PLANNING

# AND METHODOLOGY

## 6.1 CONCLUSION

According to the design and Algorithms proposed in the report we come to a conclusion that the we can automate the detection of products using digital image processing and sorting them using a controller which are passing over the conveyor. We sort the products with high accuracy, good repeatability and high productivity. Using Digital Image Processing in the system we can detect the products based on shape, colour and texture. Further the products are sorted according to its type into different conveyors for packaging.

## 6.2 FUTURE SCOPE

Future work that can be implemented in this project is, we can extend the single camera inspection into multi line camera inspection thereby increasing the accuracy. We can implement this in other fields by changing simple software and hardware. It can be implemented in quality control of products before final dispatch.

## 6.3 SCHEDULE

Week 1 (28-01-23): Group formation and problem statement search.

Week 2 (03-02-23): Project topic finalization.

Week 3 (10-02-23): Problem solving and circuit designing.

Week 4 (17-02-23): Component availability check according to circuits.

Week 5 (24-02-23): Finalizing circuit diagram with available components.

Week 6 (03-03-23): PCB Designing.

Week 7 (10-03-23): Purchased Enclosure and adjusted PCB size.

Week 8 (17-03-23): Finalizing PCB Artwork.

Week 9 (24-03-24): Manufacturing PCB.

Week 10 (31-03-23): Assembling components on PCB and Testing.

Week 11 (08-04-23): Optimizing code and LCD Daughterboard design.

Week 12 (13-04-23): Code correction and testing.

Week 13 (21-04-23): Final PCB fitting in enclosure and project review.

Week 14 (28-04-23): Project Presentation.

## REFRENCES:

[1] Amir Deshmukh, ”Design & Development of Automatic Conveyor Controlling System for Sorting of Component on Color basis”, International Journal of Science and Research (IJSR), Index Copernicus Value (2013): 6.14 | Impact Factor (2014): 5.611.
[2] Nikam Devendra ,” Automation of Object Sorting Using an Industrial Roboarm and MATLAB Based Image Processing”, International Journal of Emerging Technology and Advanced Engineering Website: www.ijetae.com (ISSN 2250-2459, ISO 9001:2008 Certified Journal, Volume 5, Issue 2, February 2015).
[3] Bikarna Pokharel ,“MACHINE VISION AND OBJECT SORTING” ,Bachelor’s thesis Degree Programme in Automation Engineering Valkeakoski, May 2013.
[4] Avadhoot R.Telepatil , “Colour Object Counting and Sorting Mechanism Using Image Processing Approach”, International Journal of Modern Trends in Engineering and Research www.ijmter.com @IJMTER-2015, All rights Reserved 308, e-ISSN: 2349- 9745 p-ISSN: 2393-8161.
[5] Shriya.M.Kumar, “Low Cost Automation for Sorting of Objects on Conveyor Belt” International Journal of Innovative Research in Science, Engineering and Technology (An ISO 3297: 2007 Certified Organization) Vol. 5, Special Issue 10, May 2016.
[6] Rahul Kumar , “Object Detection and Recognition for a Pick and Place Robot”, Conference Paper· November 2014 ,Research Gate.
[7] www.raspberrypi.org
[8] www.opencv.org
[9] www.microchip.com
[10] www.python.org

Page PAGE 9 MMCOE - B. E. ELECTRONICS AND TELECOMMUNICATION

Page 10 MMCOE - B. E. ELECTRONICS AND TELECOMMUNICATION

Page PAGE 19 MMCOE - B. E. ELECTRONICS AND TELECOMMUNICATION

Page 20 MMCOE - B. E. ELECTRONICS AND TELECOMMUNICATION

Page PAGE 27 MMCOE - B. E. ELECTRONICS AND TELECOMMUNICATION

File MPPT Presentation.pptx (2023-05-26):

## Marathwada Mitra Mandal’s College Of Engineering Pune Accredited with ‘A++' Grade by NAAC

Project Title
“Maximum Power Point Tracker with Controlled Opto-isolated
Solid-state outputs and function-driven status display”
Project Guide
Prof. Jitendra Bakliwal

BY

Advait Thale (T190453143)

Mansi Veer (T190453148)

## Outlines

- Introduction
- Literature Survey
- Tools Requirement
- Specifications
- Block Diagram and Working
- Flowchart and Algorithm
- Conclusion
- Future Scope
- Schedule
- References

## Introduction

Maximum Power Point Tracking (MPPT) is a crucial technique employed in photovoltaic (PV) systems to optimize the power output of solar panels by dynamically adjusting the operating point to the MPPT under varying environmental conditions. The performance of MPPT algorithms can be influenced by various factors, including system design, algorithm selection, sensor accuracy, tracking speed, and adaptability to different environmental conditions. MPPT algorithms can be implemented in hardware using microcontrollers, digital signal processors (DSPs), or specialized MPPT controller ICs.
Implementation of MPPT with QR topology requires careful consideration of circuit layout, component selection, and control strategy to achieve optimal performance.
An Opto-isolator also known as an optocoupler is an electronic device that provides electrical isolation between two circuits using light. It consists of an LED (light-emitting diode) on one side and a photodetector (typically a phototransistor) on the other side.
A solid-state relay is an electronic switch that uses semiconductor devices (such as MOSFETs or thyristors) to control the flow of current without any mechanical parts. The SSR should have sufficient current and voltage ratings to handle the desired load.

## Literature survey

The literature survey presents an overview of the Maximum Power Point Tracker, Controllable Opto-isolated Solid state outputs, and function scrolling on LCD. The journals were analyzed and content was presented with ideas that were focused on improvising the existing system and trying to implement a cost-efficient alternative to existing MPPTs. IOT-based microcontrollers have been applied in domestic, medical, industrial, and security fields and in remote monitoring.
We have used the ESP32 microcontroller for controlling and monitoring all the ongoing operations and also used C and C++ programming languages as the whole ESP program environment is built on them and they are the most efficient programming languages for writing libraries and efficiently compiling the program.
A 16*2 character LCD placed atop the enclosure is used to display the voltage, current, and temperature parameters of the battery and produced voltage from the PV panels settings menu on the display voltage control.

## Requirement Tools

- Software:-
- Proteus
- VS Code
- Platform IO Plugins
- Arduino IDE
- Hardware:-
- ESP32
- IR Receiver
- LM7805
- 16*2 LCD
- 6V lead acid battery
- IRFZ44
- Photovoltaic Panel
- 2N2222A

## Specifications

- ESP32:
- Single or dual-core 32-bit LX6 Microprocessor with clock frequency up to 240 MHz.
- 34 Programmable GPIOs.
- Supports both Classic Bluetooth v4.2 and BLE specifications.
- Motor PWM and up to 16 channels of LED.
- Secure boot and flash encryption.
- IR Receiver:
- Receives data at 38kHz of carrier frequency.
- The data rate of TSOP1738 is up to 2400bps.
- TSOP is used to receive data that supports various transmitter code.

## Specifications

- 4V Acid Battery:
- It is a Valve-regulated lead-acid battery.
- Nominal voltage: 4V.
- Nominal capacity: 1Ah.
- Charging Voltage: 4.8V to 5.2V.
- Long-lasting battery and minimal maintenance required.
- LM7805:
- 3-terminal Regulators.
- Output Current up to 1.5A.
- Internal Thermal-Overload Protection.
- High Power-Dissipation Capability.
- Internal Short-Circuit Current Limiting.

## Specifications

- IRFZ44:
- The minimum gate threshold voltage is 2V.
- Maximum gate threshold voltage is 4V.
- Pulsed Drain Current (ID peak) is 160A.
- Continuous Drain Current (ID)IS 49A at 25°C
- Small signal N-Channel MOSFET.

## Block Diagram and Working

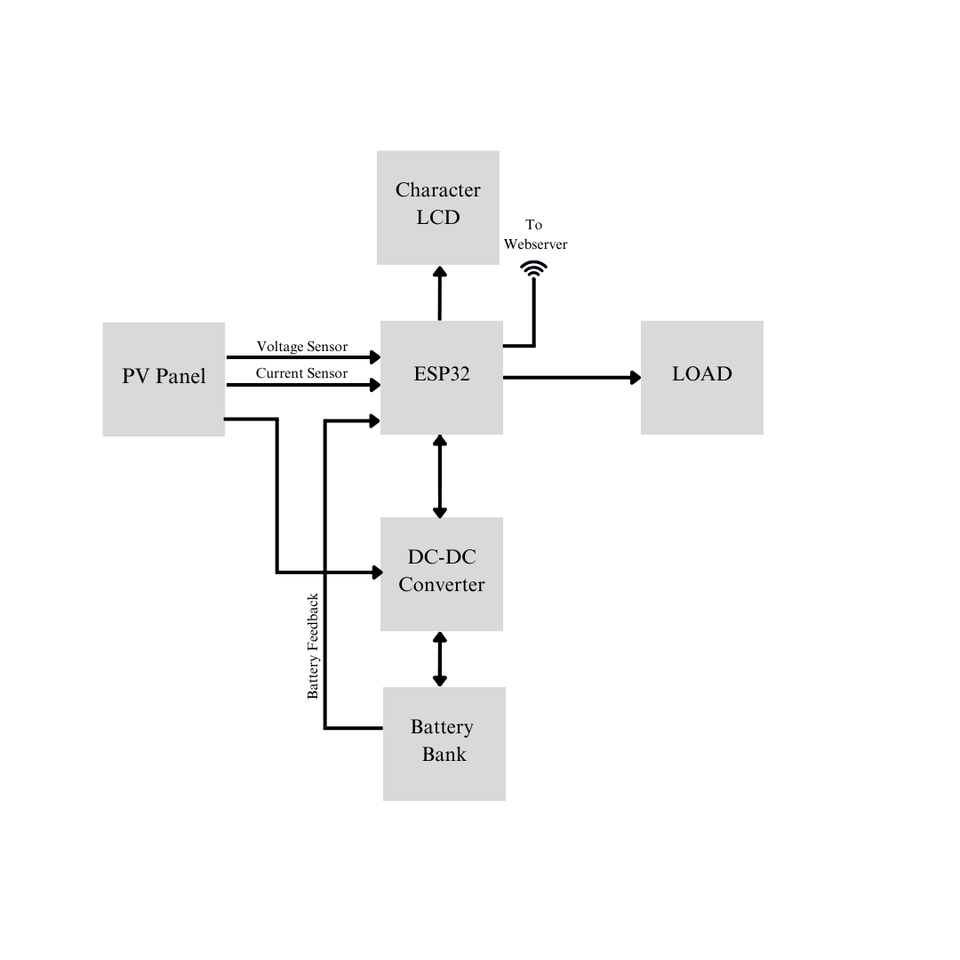
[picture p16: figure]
A diagram of a power supply system

## Working

- The ESP32 is used to control all the important tasks for charging/ using battery bank, to monitor the voltage and current of battery and power generated by PV Panels. The obtained data can be viewed on the character LCD atop of the MPPT enclosure as well as on the webserver in real time. With the help of connected current sensor and ADC, it constantly checks how much voltage is being generated by photovoltaic panels, current flowing through the batteries or battery bank, temperature of battery bank along with cut-off protection in case of battery overheating. The two MOSFET controlled outputs can be used for connecting DC load of 12V Max. The outputs are normally controlled by microcontroller at normal MPPT operations but can be manually controlled by IR remote. If the battery is overheated or is fully charged in those intervals various alerts occur. A header port for KY040 rotary encoder is kept for controlling the output load voltage and battery charge parameters. Also, a header for inverter is routed on the PCB for Inverter daughterboard for further expansion.

## Circuit Diagram


## PCB Artwork of Main Board

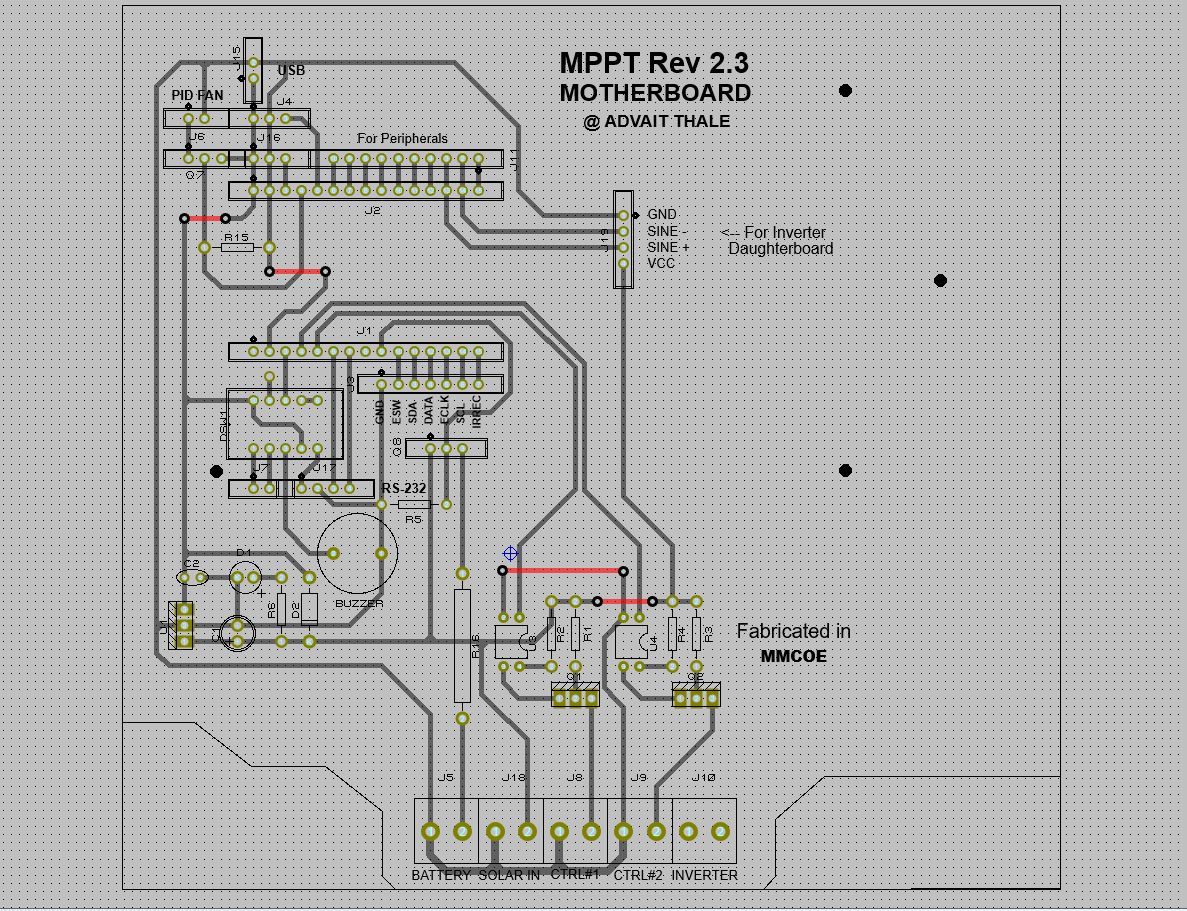
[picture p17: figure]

## PCB Layout of LCD Daughterboard


## 3D Render of Main Board


## 3D Render of LCD Daughterboard

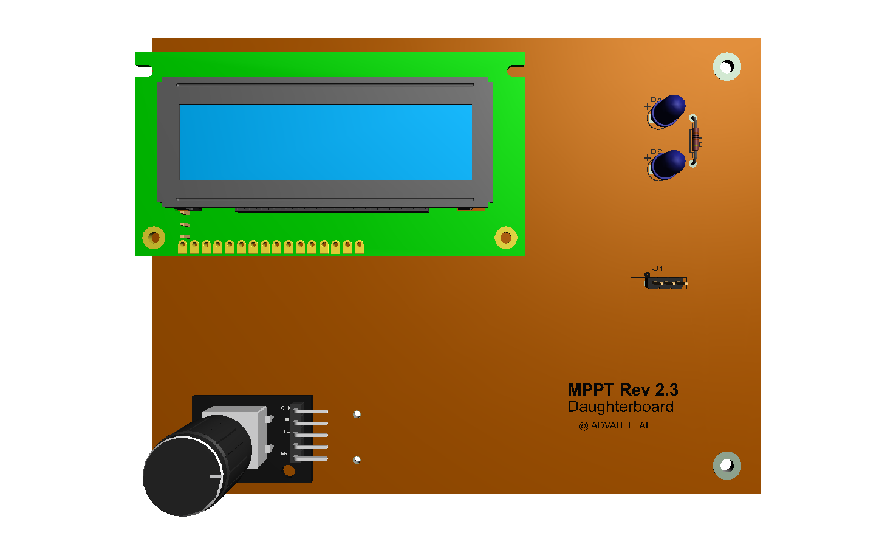
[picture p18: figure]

## Conclusion

- Thus, we have demonstrated a working prototype of Output controllable MPPT with Webserver. It shows the Battery charging parameters such as voltage, current across and input power parameters on the character LCD as well as can be viewed on the Webserver by connecting to ESP32 via Wi-Fi and browsing 192.168.1.1 address on the internet browser such as Chrome, Edge, etc. We tried to improve productivity and efficiency of already available device in the market and concluded that it is doable. The data obtained provides high accuracy, good repeatability and increases productivity.

## Future Scope

Future research can focus on developing advanced control algorithms for MPPT with QR topology. This includes the integration of AI Techniques such as machine learning, neural networks, and can be explored in the context of energy storage systems including incorporating battery storage, supercapacitors, or hybrid energy storage technologies to improve the overall efficiency, stability and reliability of renewable energy systems.
MPPT with QR topology can be integrated into hybrid renewable energy systems that combine multiple sources such as solar, wind and storage.

## Schedule

- Week 1 (27-1-23): Group formation and problem statement search.
- Week 2 (3-2-23): Project Topic finalization.
- Week 3 (10-2-23): Problem-solving and circuit designing.
- Week 4(17-2-23): Component availability checks according to a circuit.
- Week 5 (24-2-23): Finalizing circuit diagram with available components.
- Week 6 (3-3-23): PCB Designing.
- Week 7 (10-3-23): Purchased Enclosure and adjusted PCB size.
- Week 8 (17-3-23): Finalizing PCB Artwork.

## Schedule

- Week 9 (2-43-23): Manufacturing PCB.
- Week 10 (31-3-23): Assembling components on PCB and Testing.
- Week 11 (8-4-23): Optimizing code and LCD Daughterboard design.
- Week 12 (13-4-23): Code correction and testing.
- Week 13 (21-4-23): Final PCB fitting in an enclosure and project review to guide.
- Week 14 (3284-23): Project Presentation.

## References

- Paul Horowitz, Winfield Hill, “Power Sources: Battery Types”, in The Art of Electronics, Second Edition, Pg. 920-931.
- D. P. Kothari, I.J. Nagrath, “Solar Energy & its Utilisation”, in Modern Power System Analysis, Fourth Edition, Pg. 32-42.
- Paul Horowitz, Winfield Hill, “Solar Cells”, in The Art of Electronics, Second Edition, Pg. 932- 933.

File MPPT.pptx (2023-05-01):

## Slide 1

## MPPT

An MPPT, or maximum power point tracker is an electronic DC to DC converter that optimizes the match between the Solar Array (PV panels), and the Battery pack.

## What is Maximum Power Point Tracking?

- The charge controller looks at the output of the panels and compares it to the battery voltage.
- It then figures out what is the best power that the panel can put out to charge the battery.
- It takes this and converts it to best voltage to get maximum AMPS into the battery.
- In Addition to this functionality,

## Schematic

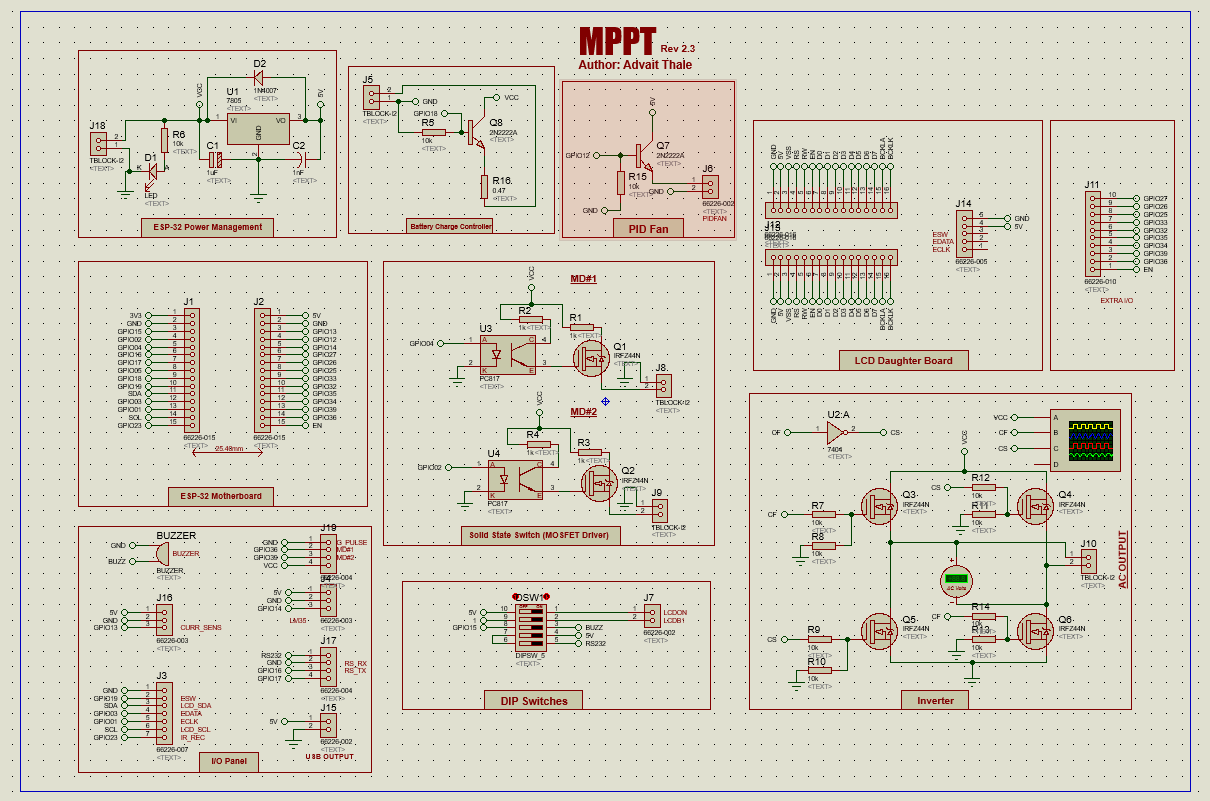
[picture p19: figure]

## Solid State Relay Outputs(MOSFET Driven)

- One thing all MPPTs lack is they don’t provide terminal of soft starter output, thus there is constant risk of damaging load or batteries.

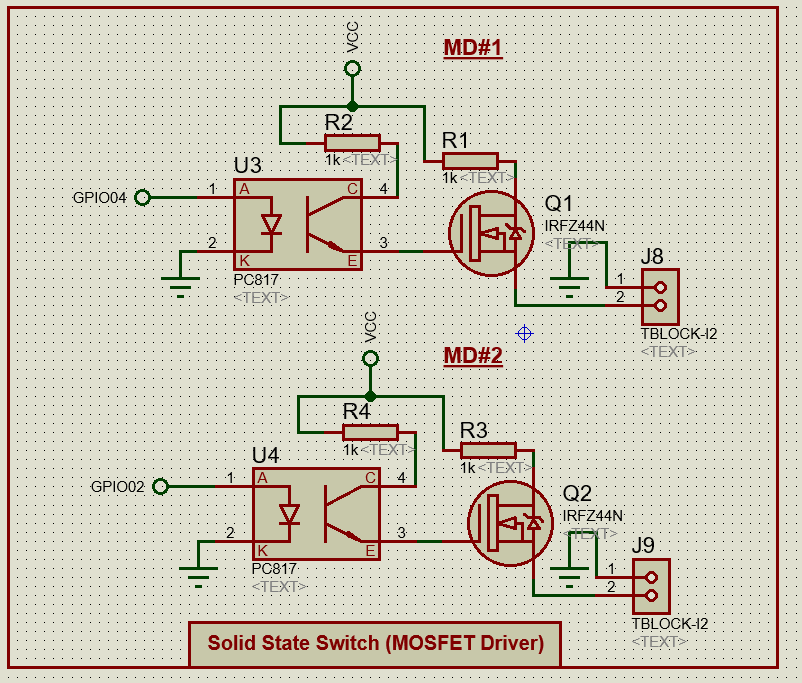
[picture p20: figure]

## ESP32 (Wi-Fi Enabled)

- All the operations are administered by ESP32 including MOSFET Drives, Status Display, all I/Os,

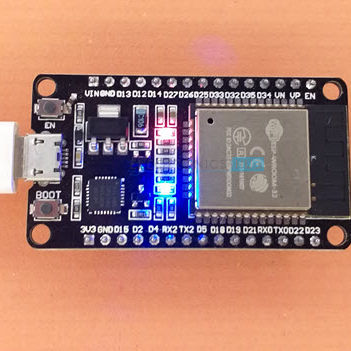
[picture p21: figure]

## Panel and Peripheral I/O

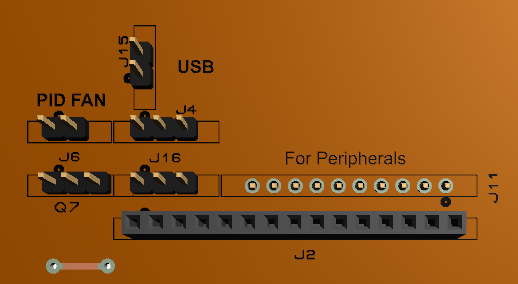
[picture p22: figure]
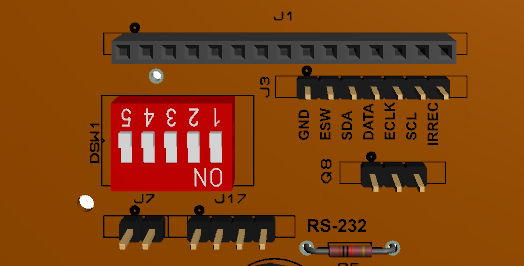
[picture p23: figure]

## PID Driven Fan

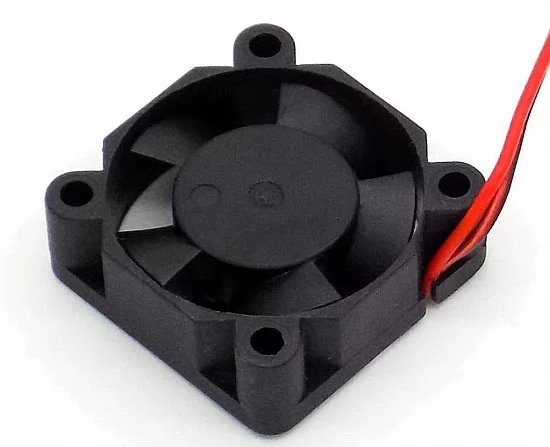
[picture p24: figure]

- To save precious power generated, the in internal cooling fan is controlled by a control system design which is PID.
- The feedback variable is set by LM35 temperature sensor, which as battery temperature increases spins fan faster.

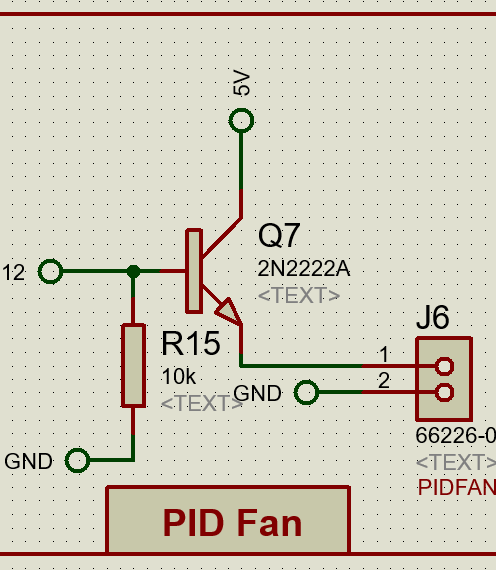
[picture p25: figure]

## PCB Artwork

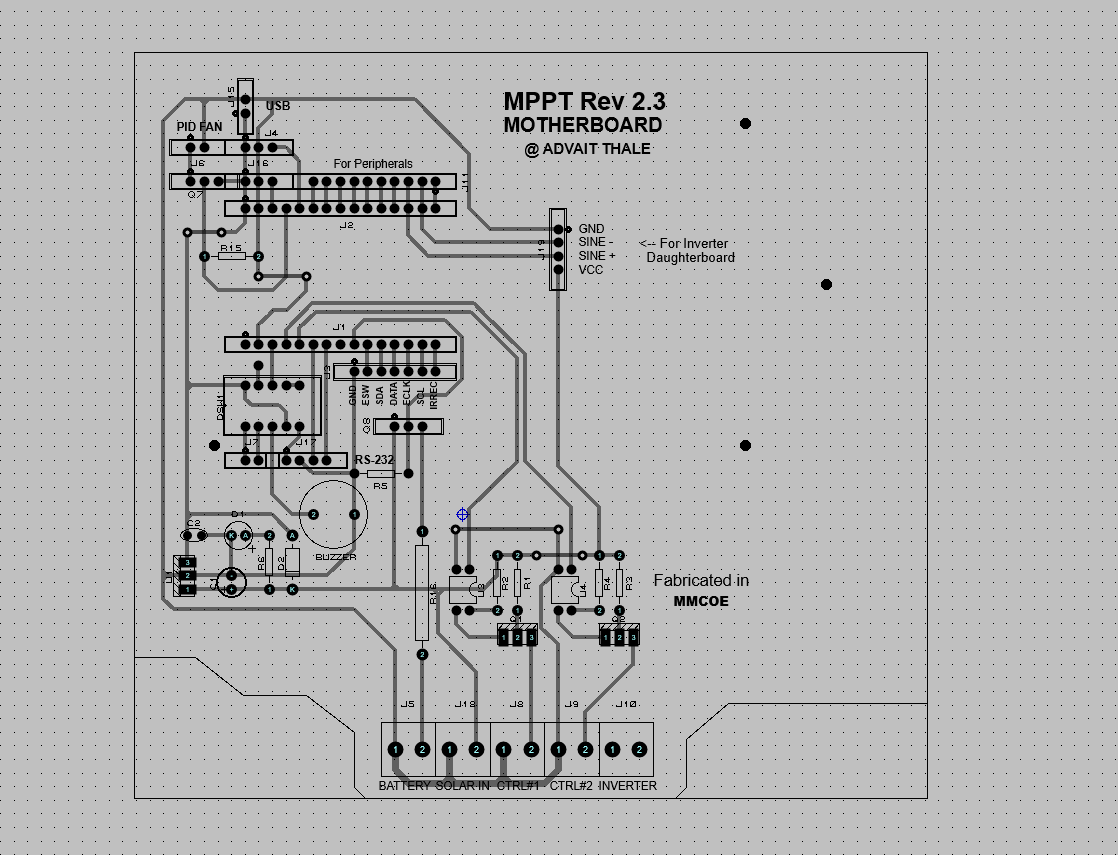
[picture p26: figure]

## Previous Prototype (#3)


## 3D Render of PCB


## Interface Daughterboard

- To display and change system variables, the status display, rotary encoder with switch and some status LEDs are mounted on separate daughterboard which will be installed on the top.
- 3D render of Interface Daughterboard shown below:

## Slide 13


## Future Expansion: Inverter Daughterboard

- The Inverter Daughterboard contains a MOSFET driven inverter to convert generated DC to AC.
- Due to space limitations Inverter is placed on separate board with control signal headers from main board.

## Additional (Automation) Features

- 2 x Software/ controlled Relay outputs (up to 240V AC)
- I/O for addition sensors (configurable)
- DIP Switches for Boot configuration & customization
- RS-232 D9 Port for Data Log (at 9600)

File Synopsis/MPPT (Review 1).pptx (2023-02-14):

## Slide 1

## MPPT

An MPPT, or maximum power point tracker is an electronic DC to DC converter that optimizes the match between the Solar Array (PV panels), and the Battery pack.

## What is Maximum Power Point Tracking?

- The charge controller looks at the output of the panels and compares it to the battery voltage.
- It then figures out what is the best power that the panel can put out to charge the battery.
- It takes this and converts it to best voltage to get maximum AMPS into the battery.
- In Addition to this functionality,

## Quasi Resonant Topology

- The width and amplitude of the pulse is fixed, and the converter is variable frequency. Thus, more power can be drawn with more pulses per second.
- One thing all MPPTs lack is they don’t provide terminal of soft starter output, thus there is constant risk of damaging load or batteries.

## Additional (Automation) Features

- 20 x 4 Character LCD for status and configuration function
- 2 x Software/ controlled Relay outputs (up to 240V AC)
- I/O for addition sensors (configurable)
- DIP Switches for Boot configuration & customization
- RS-232 D9 Port for Data Log (at 9600)
- QR MOSFET Driver Output

## Prototype (#3)


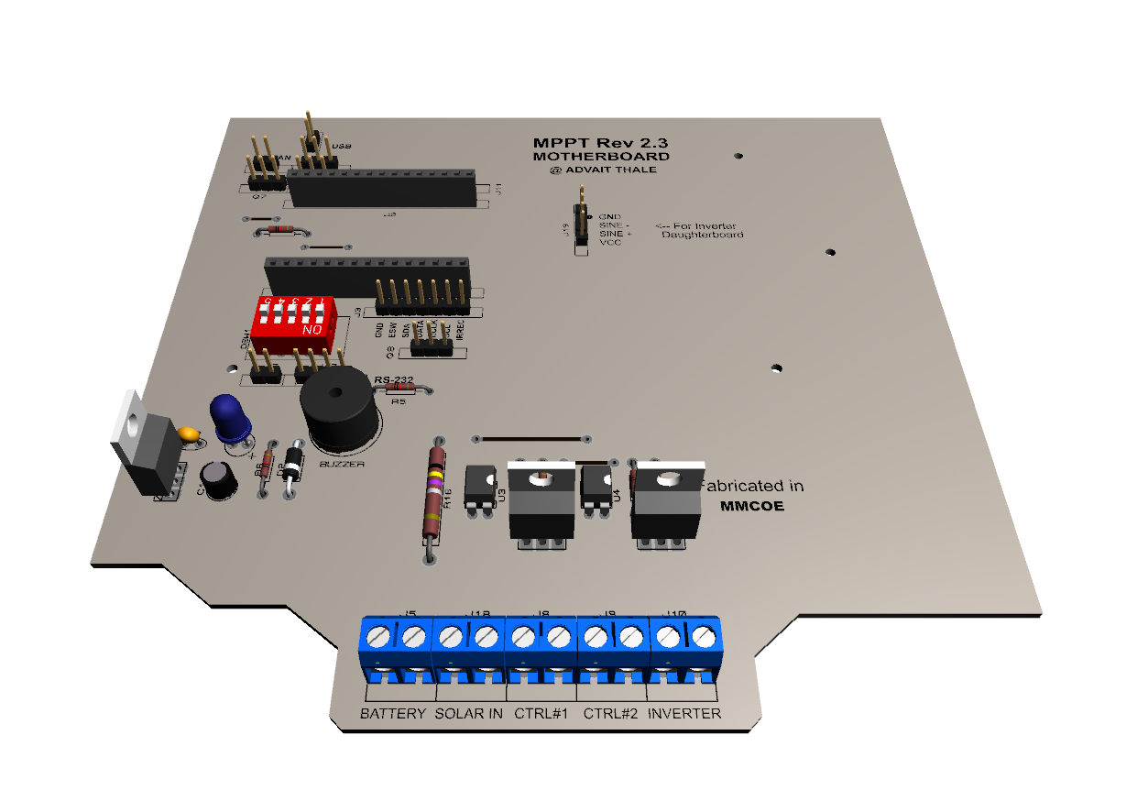
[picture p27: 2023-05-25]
Final Review/Isometric View.PNG

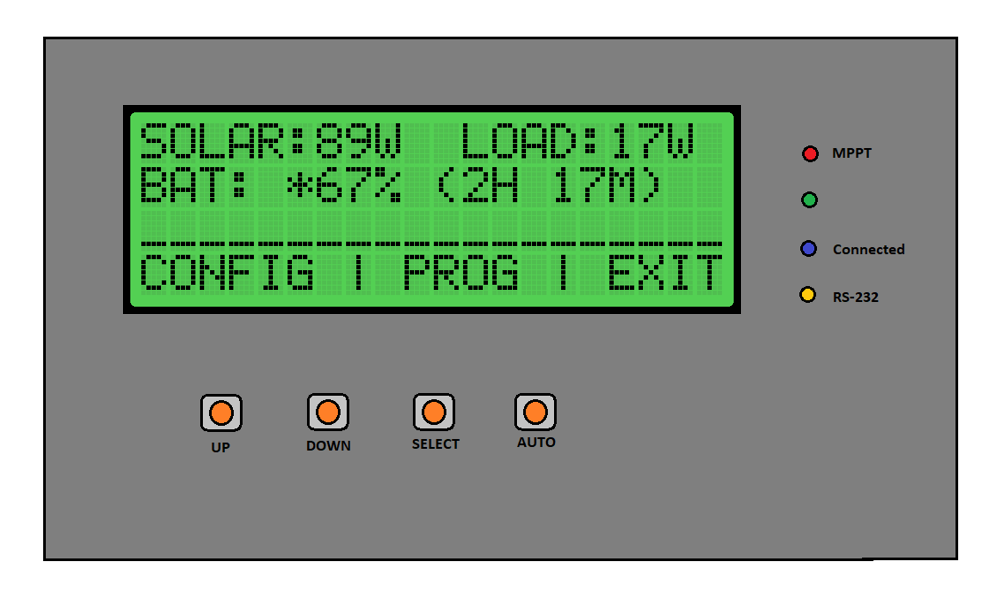
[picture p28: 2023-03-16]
Synopsis/MPPT (#3).PNG

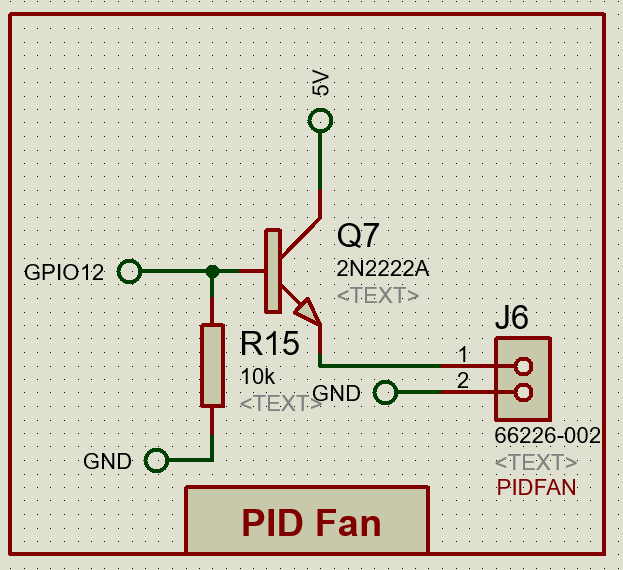
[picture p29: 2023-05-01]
Final Review/pid.PNG

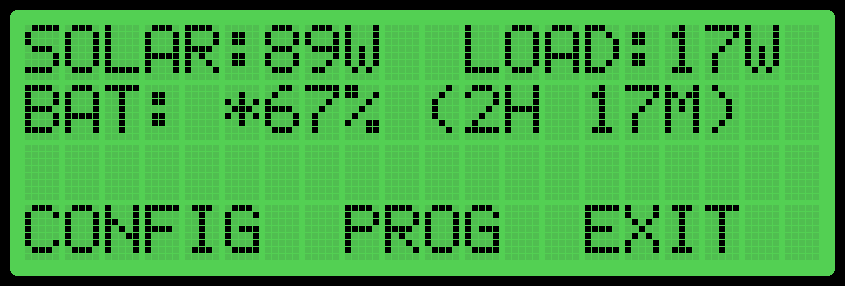
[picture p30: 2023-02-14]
Synopsis/screenshot.png

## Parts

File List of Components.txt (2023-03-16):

**************************************************************************************************

					Maximum Power Point Tracker with Low EMI Quasi-Resonant 
					Topology added to Hardware controlled 240V AC opto-isolated 
					outputs and function driven status display

**************************************************************************************************

Solar Power Unit (MPPT)

exactly refer ECOFLOW DELTA PRO or BLUETTI POWER SYSTEM

Multiple wifi controlled outputs as TBlock connectors for warm white lighting,etc
 
ESP8266
LCD for display and control (wake pin for low power mode - turn off lcd) Or Use OLED 
Refer Bluetti and purgola video

WiFi:
-power generated (Incoming)
-power consumed (Outgoing)
-outdoor and indoor temp (2 x PT-100)
-status
-battery health (if any)
-tacticle button/s control for display config 
-USB control for fairy lights
-7 Seg Display for maintenance purpose >>> Err, F, combination byte shift using single pin of uC
-RS232 interface

DIP switch seperate breakout board angled @ 90^
LCD I2C jumper and vcc for 2xDIP control
LCD breakout board along with function buttons locked relimate connector

Max. current RED alert (CURRENT OVERSHOOT)
XT60 Male (inside the unit) and Female (from Solar panels)
Fuse 30A (fuse holder-30mm)

Research about BUSBAR

*DC to AC Pure Sine wave inverter*
IC4047 multivibrator
irfz44
12-0-12 to 240V transformer

Shopping links:

XT90E-M Battery Plug Gold-Plated Male Connector:
(The XT90E-Mis completely compatible with original XT60 connectors so you can use them straight away)

https://roboticsdna.in/product/xt90e-m-battery-plug-gold-plated-male-connector-black/?src=google&kwd=&adgroup={adgroup}&device=c&campaign={campaign}&adgroup={adgroup}&keyword=&matchtype=&gclid=CjwKCAiA2fmdBhBpEiwA4CcHzcqQUSdea6Bs01_OV3jPHbGntjlg4xlgJibYuFLUYpYIvesG-jrNlBoCXkUQAvD_BwE

XT60 Male-Female Connector Pair:

https://www.electronicscomp.com/xt60-male-female-connector-pair-for-lipo-battery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

Fuse Holder - 30mm:

https://www.electronicscomp.com/fuse-holder-30mm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

(IF NECESSARY) 
DC 5V 3010 Cooling Fan - 30x30x10 mm Size:

https://www.electronicscomp.com/dc-5v-3010-cooling-fan-30x30x10-mm-size

4 Inch Fan Grill - 120mm:

https://www.electronicscomp.com/4-inch-fan-grill-120mm

https://robu.in/product/micro-sd-card-module/?gclid=EAIaIQobChMIyLee9rnd_QIVlw4rCh3XOgFLEAQYBiABEgICYfD_BwE

https://robu.in/product/rs232-to-ttl-serial-interface-module/

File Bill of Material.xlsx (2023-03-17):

Item | Count | SP | GST (+18%) | Total
ESP-32 Dev Module | 1
Rotary Encoder | 1
RS232 to TTL Module | 1
IRFZ44N MOSFET | 6
IC7805 Voltage Regulator | 1
5x DIP Switch | 1
Capacitor
Resistors
100
1K
10K

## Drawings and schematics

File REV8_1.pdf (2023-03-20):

## DSW1

Q1

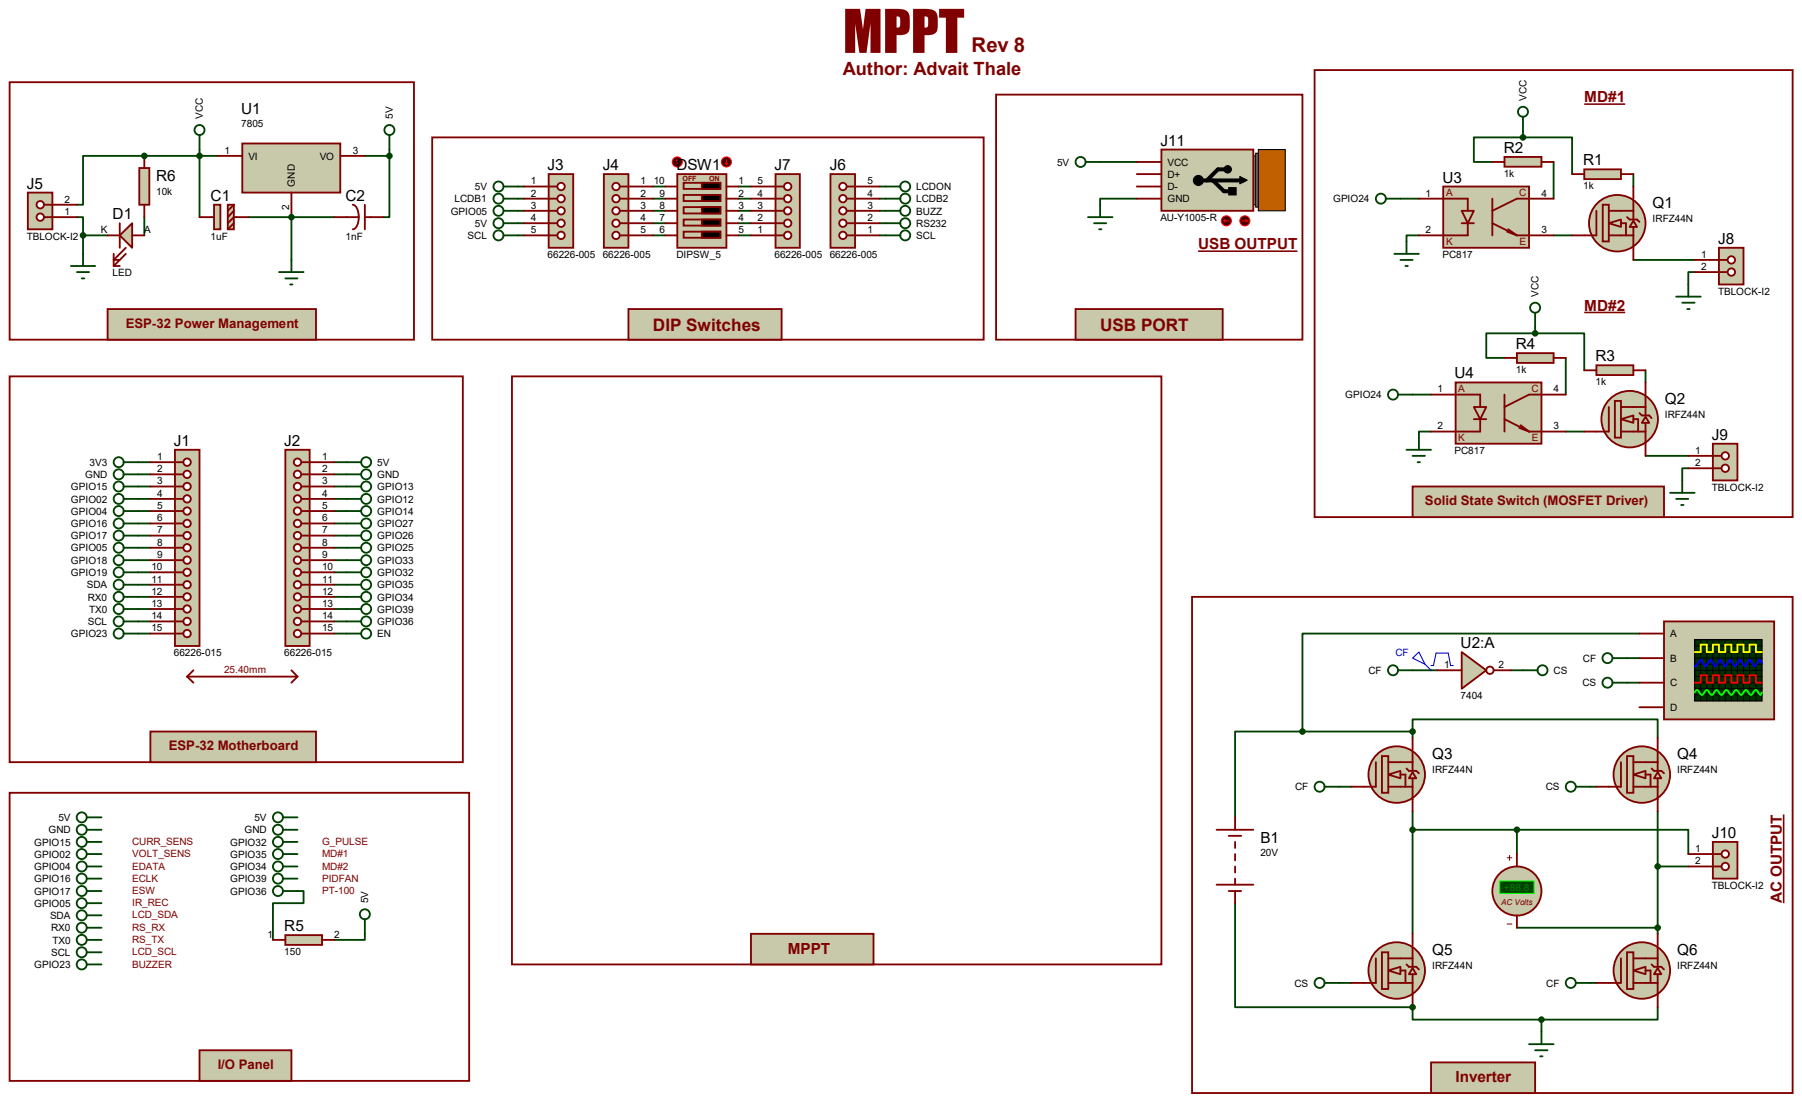
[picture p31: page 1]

Solid State Switch (MOSFET Driver)

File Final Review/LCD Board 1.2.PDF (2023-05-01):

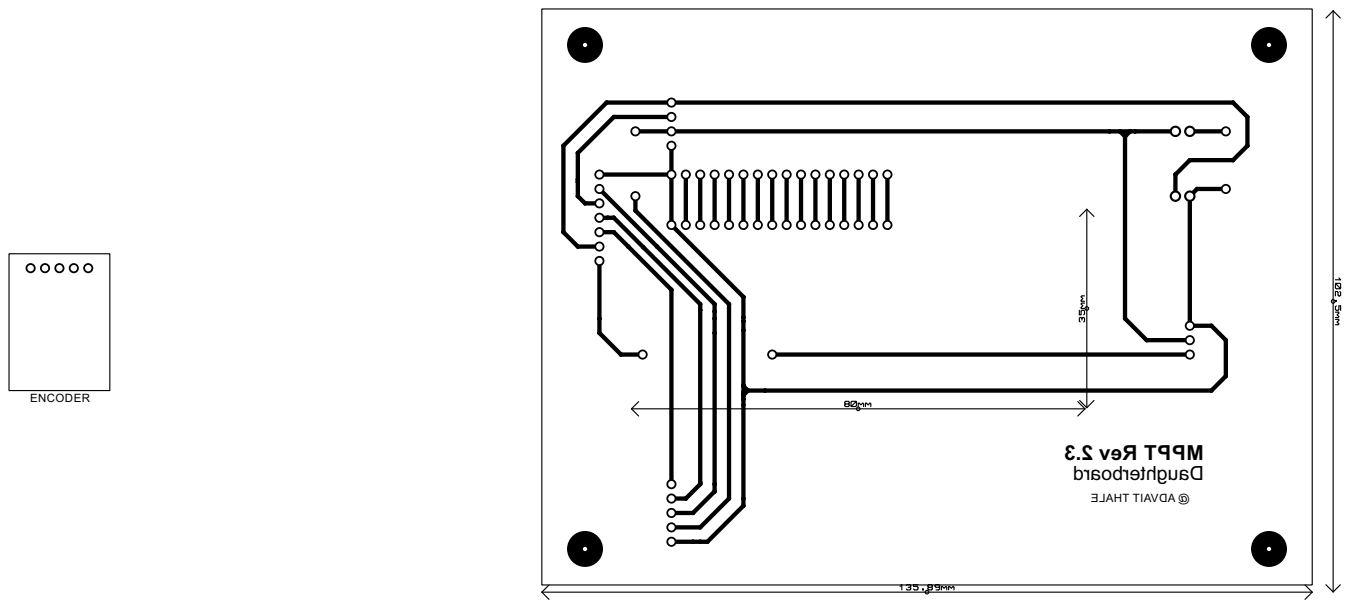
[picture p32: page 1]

3. 2 ve R TPP M dr aobr et hgua D ELAHT TI AVDA @ ENCODER

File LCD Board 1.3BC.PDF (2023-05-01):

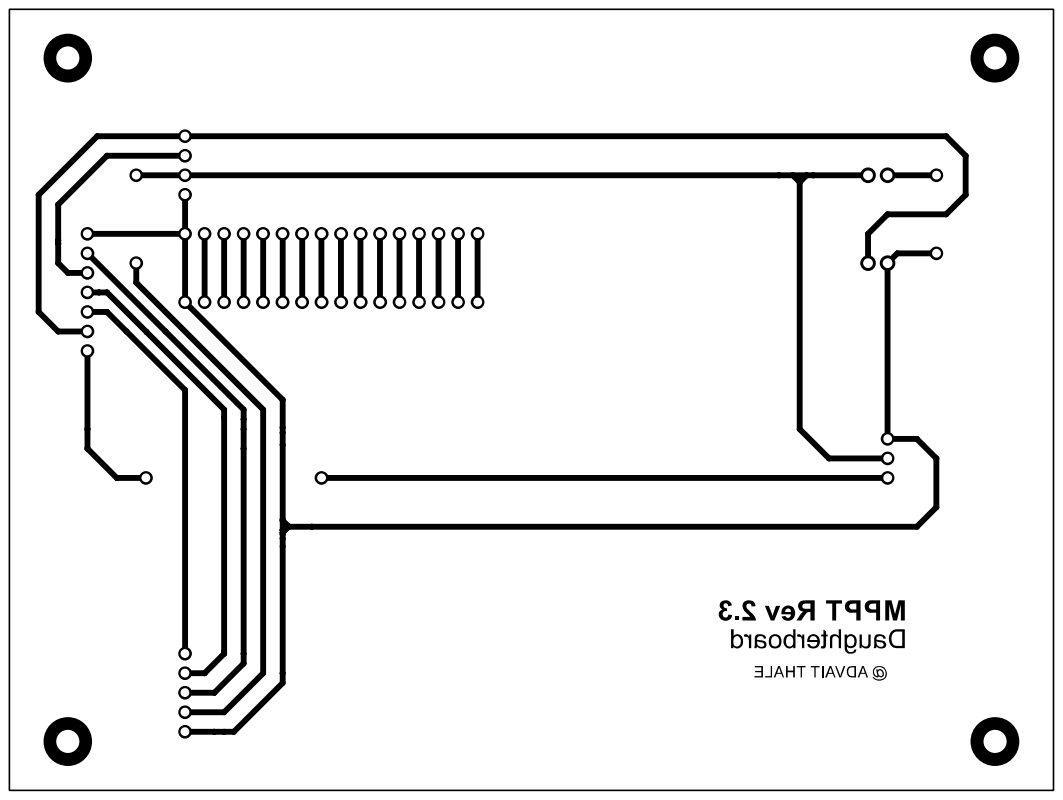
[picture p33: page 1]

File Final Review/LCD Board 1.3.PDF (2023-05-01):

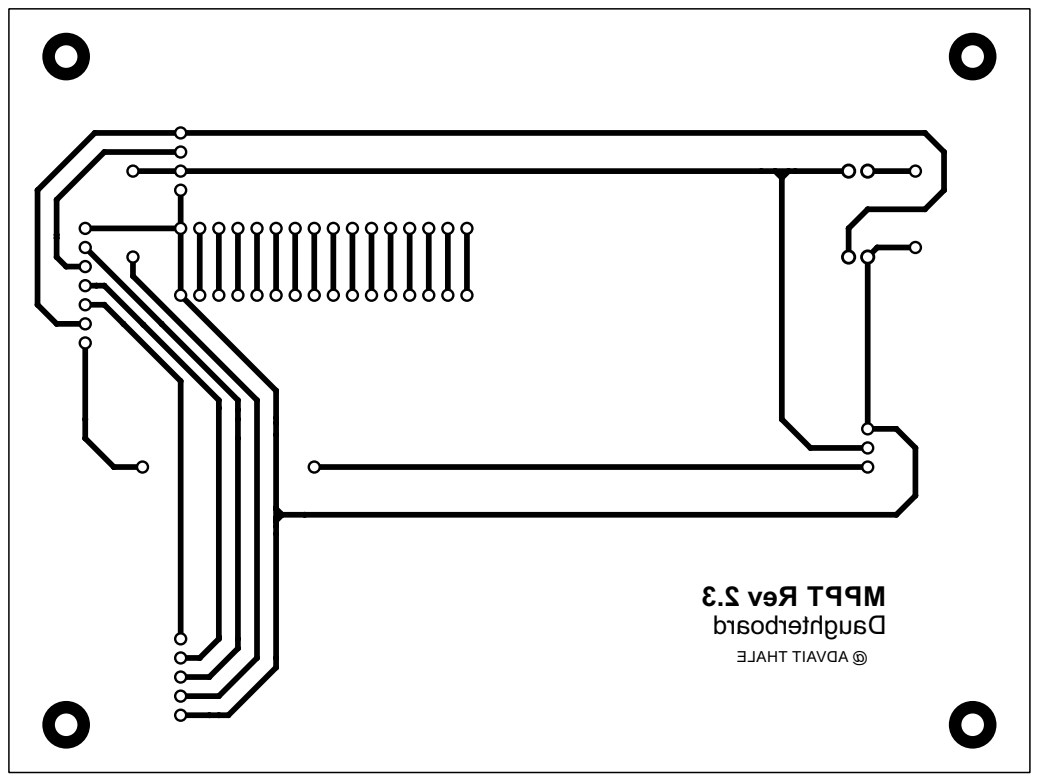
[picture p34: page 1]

dr aobr et hgua D

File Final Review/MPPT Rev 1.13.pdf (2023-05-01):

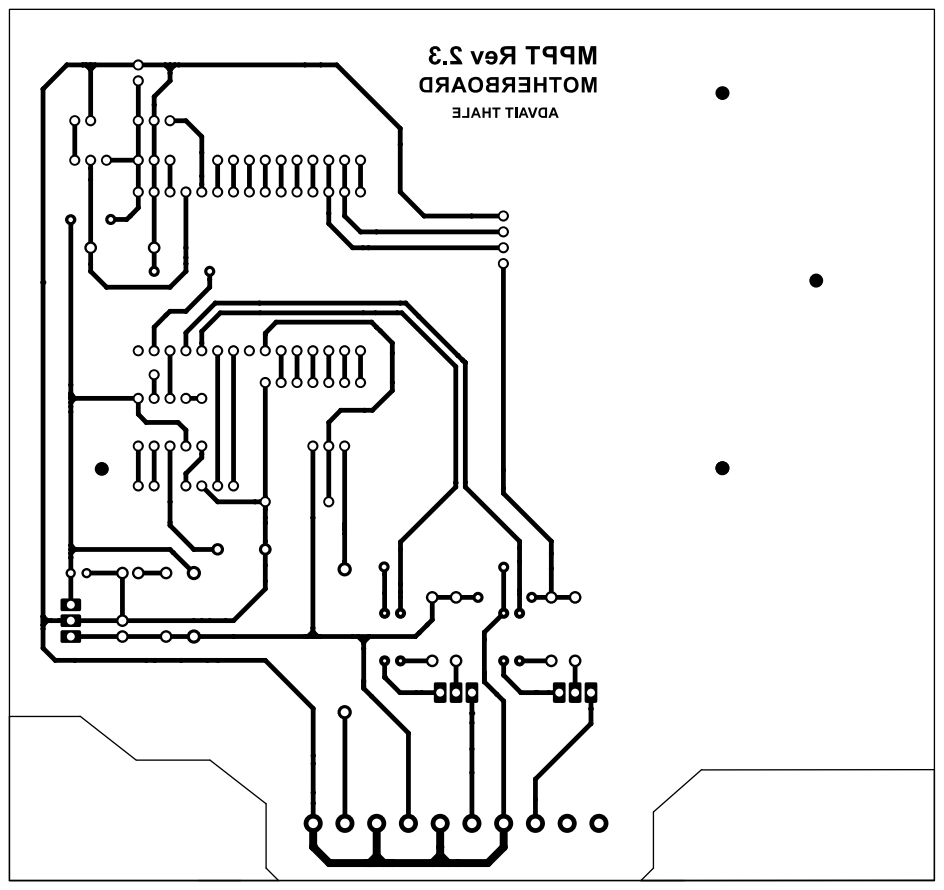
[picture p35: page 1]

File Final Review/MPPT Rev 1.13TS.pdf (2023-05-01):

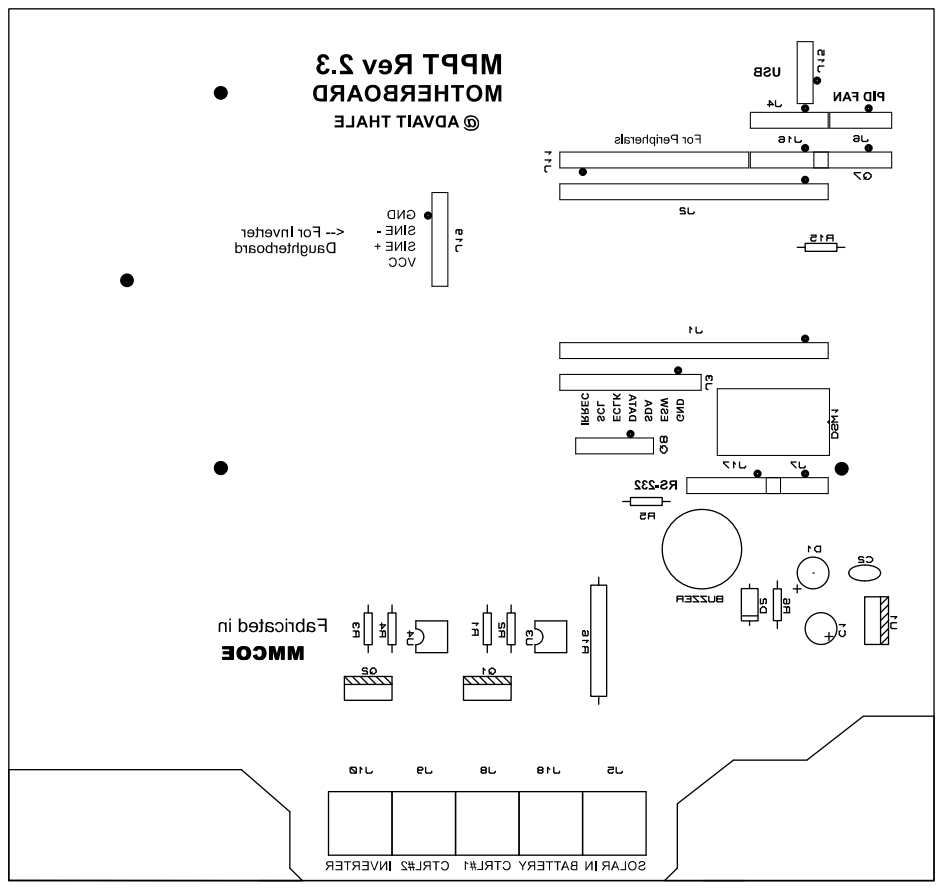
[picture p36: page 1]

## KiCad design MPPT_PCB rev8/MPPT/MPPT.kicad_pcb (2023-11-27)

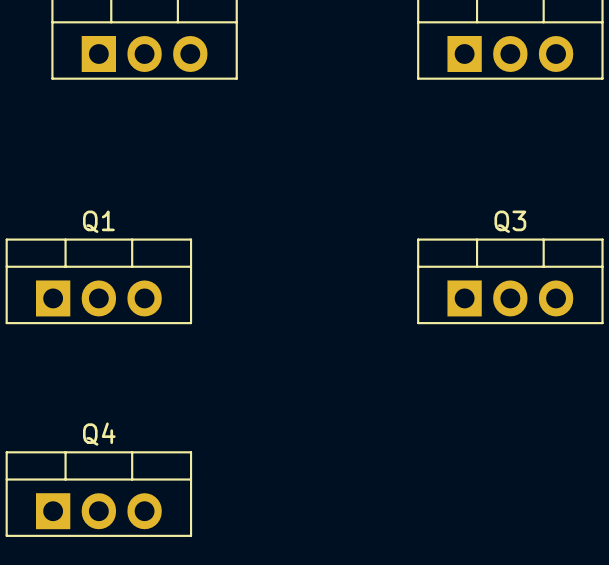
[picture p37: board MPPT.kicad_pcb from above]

Board: 2 copper layers, 5 parts (0 on the bottom side), 5 nets, no tracks yet.

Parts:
Q1, Q2, Q3, Q4, Q5: IRLZ44N; TO-220-3_Vertical

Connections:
unnamed: Q1.2 (D), Q4.2 (D)
unnamed: Q1.3 (S), Q2.2 (D), Q3.2 (D)
unnamed: Q2.1 (G), Q3.1 (G), Q4.1 (G)
unnamed: Q2.3 (S), Q3.3 (S), Q5.3 (S)
unnamed: Q4.3 (S), Q5.2 (D)

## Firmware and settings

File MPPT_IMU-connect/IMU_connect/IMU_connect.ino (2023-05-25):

/*
  Author: Advait Thale
  Board: ESP32 Dev Module
  Baud: 115200
  Flash Freq: 80MHz

  *************************************************************************************************
                                         MPPT_PORT-Xtensa
  *************************************************************************************************

  This test code is an overview of how MPPT works on the port of ATMega328P.
  It is equipped with 20*4 Character LCD (for device & energy status), Function
  Buttons, ESP32 Microcontroller, Solar Inlet, 30A FUSE, Sleep Mode, Webserver,
  2 x PT-100(for Indoor & Outdoor Temp.), RS-232 Interface(at 9600),Program
  Serial(at 115200), Internal DIP Switches (for system configuration), Relay
  driven Outputs(for automation purpose), I/O for interfacing external
  sensors and automation purpose.
  The live status is displayed on LCD, the Webserver(at 192.168.1.1) as well as
  the data log can be viewed via both RS-232 (DB9) or USB A Serial ports. Refer
  README.md and attached datasheets for furthur details on MPPT.

  **************************************************************************************************
  *                                        ESP32 PINOUT                                            *
  **************************************************************************************************

                               3V3 |*|                       |*| 5V
                               GND |*|                       |*| GND
                              BUZZ |*| GPIO15         GPIO13 |*| ACS712
                              MD#1 |*| GPIO02         GPIO12 |*| PIDFAN
                              MD#2 |*| GPIO04         GPIO14 |*| LM35
                              RX   |*| GPIO16         GPIO27 |*|  -
                              TX   |*| GPIO17         GPIO26 |*|  -
                               -   |*| GPIO05         GPIO25 |*|  -
                              C.C. |*| GPIO18         GPIO33 |*|  -
                              ESW  |*| GPIO19         GPIO32 |*|  -
                              SDA  |*| GPIO21         GPIO35 |*|  %
                             EDATA |*| GPIO03         GPIO34 |*|  %
                             ECLK  |*| GPIO01         GPIO39 |*| SINE-
                              SCL  |*| GPIO22         GPIO36 |*| SINE+
                             IRREC |*| GPIO23           EN   |*|  -

  ***************************************************************************************************

*/

//#include <Arduino.h>
#include <LiquidCrystal_I2C.h>
//#include <IRremote.h>
#include <ACS712.h>
#include <WiFi.h>
#include <WebServer.h>

// Local SSID
#define WIFI_SSID "MPPT Rev 2.3"
#define WIFI_PASSWORD "Mppt_N3t"

// Network SSID
// #define WIFI_SSID "Issac Newton 🍎"
// #define WIFI_PASSWORD "amhipuneri"

/* Put IP Address details */
IPAddress local_ip(192, 168, 1, 1);
IPAddress gateway(192, 168, 1, 1);
IPAddress subnet(255, 255, 255, 0);
WebServer server(80);

#define CUR 13     // ACS712
#define MOSFET_1 2 // MOSFET Driver Opto-Isolator 2 // Built-In LED Pin
#define MOSFET_2 4 // MOSFET Driver Opto-Isolator 2
#define BUZZ 15    // External Buzzer
#define LM 14      // LM-35
#define IREC 23    // IR Receiver
#define PBJT 18    // Battery Charge Control BJT
#define BVOL 34    // Battery Voltage ADC
#define SVOL 35    // Input Voltage ADC
#define dt 2000

int RAW_TEMP, BAT_VOL, SOL_VOL, PLAY = 0;
float BAT_VOL_R_FACT, SOL_VOL_R_FACT = 0.09;
float PID_TEMP, BAT_CURRENT, BAT_VOLTAGE, SOL_VOLTAGE;

byte TEMP[] = {0x04, 0x0A, 0x0A, 0x0A, 0x0E, 0x1F, 0x1F, 0x0E};    // Thermometer Character
byte CELSIUS[] = {0x18, 0x18, 0x07, 0x08, 0x08, 0x08, 0x08, 0x07}; // Modified °C Character
byte BATTERY[] = {0x0E, 0x11, 0x11, 0x1F, 0x1F, 0x1F, 0x1F, 0x1F}; // Battery Character
byte PANEL[] = {0x1F, 0x15, 0x1F, 0x15, 0x1F, 0x15, 0x1F, 0x00};   // PV Panel Character

LiquidCrystal_I2C lcd(0x27, 16, 2);
//ACS712 sensor(ACS712, 13);
ACS712  ACS(13, 3.3, 4095, 185); //  ACS712 5A  uses 185 mV per A

void greetings();
void SOLAR_INFO();
void BATTERY_INFO();
void handle_OnConnect();
void handle_NotFound();
//String SendHTML();

void tone(byte PIN, int FREQ)
{
  ledcSetup(0, 2000, 8);
  ledcAttachPin(PIN, 0);
  ledcWriteTone(0, FREQ);
  PLAY = PIN;
}

void noTone()
{
  tone(PLAY, 0);
}

void setup()
{
  Serial.begin(115200);
  pinMode(CUR, INPUT);       // ADC Pin for ACS712
  pinMode(BVOL, INPUT);      // ADC Pin for Battery Voltage
  pinMode(SVOL, INPUT);      // ADC Pin for Input Voltage
  pinMode(MOSFET_1, OUTPUT); // MOSFET Driver Pin A
  pinMode(MOSFET_2, INPUT);  // MOSFET Driver Pin B
  pinMode(BUZZ, OUTPUT);     // Buzzer Pin for Beeps
  pinMode(LM, INPUT);        // ADC Pin for LM35 Temp.
  pinMode(IREC, INPUT);      // IR Receiver VS1838B
  lcd.init();                // LCD Initialise
  lcd.backlight();           // LCD Backlight ON
  WiFi.mode(WIFI_AP);
  WiFi.softAP(WIFI_SSID, WIFI_PASSWORD); // Set it to NULL, if you don’t want to set a password.
  WiFi.softAPConfig(local_ip, gateway, subnet);
  delay(100);
  Serial.print("Connecting ");
  greetings(); // Device Start Configuration
  server.on("/", handle_OnConnect);
  server.onNotFound(handle_NotFound);
  server.begin();
}

void loop()
{
  server.handleClient();
  SOLAR_INFO();
  delay(dt);
  BATTERY_INFO();
  delay(dt);
}

void handle_OnConnect()
{
  loop();
  server.send(200, "text/html", SendHTML(SOL_VOLTAGE, BAT_CURRENT, PID_TEMP, BAT_VOLTAGE));
}

void handle_NotFound()
{
  server.send(404, "text/plain", "Device is Not Connected to ESP32!!");
}

void greetings()
{
  lcd.setCursor(0, 0);
  lcd.print("MPPT Rev 2.3");
  lcd.setCursor(0, 1);
  lcd.print("----------------");
  Serial.println("Initializing MPPT...");
  // digitalWrite(MOSFET_1, HIGH);
  digitalWrite(BUZZ, !digitalRead(BUZZ));
  delay(85);
  tone(BUZZ, 4093);
  delay(200);
  noTone();
  digitalWrite(BUZZ, !digitalRead(BUZZ));
  delay(100);
  delay(dt);
  lcd.clear();
}

void SOLAR_INFO()
{
  lcd.createChar(9, TEMP);
  lcd.createChar(10, CELSIUS);
  lcd.createChar(11, PANEL);
  lcd.home();
  SOL_VOL = analogRead(SVOL);
  SOL_VOLTAGE = SOL_VOL * (4.0 / 4096) * 10;
  BAT_CURRENT = (ACS.mA_DC() / 1000);
  RAW_TEMP = analogRead(LM);           // Read LM ADC
  PID_TEMP = ((RAW_TEMP * 1.22) / 10); // Convert ADC value to equivalent voltage and divide since LM35 gives output of 10mv/°C*/
  lcd.setCursor(0, 0);
  lcd.print("VOL:");
  lcd.setCursor(4, 0);
  lcd.print(SOL_VOLTAGE);
  lcd.setCursor(8, 0);
  lcd.print("V");
  lcd.setCursor(10, 0);
  lcd.write(9);
  lcd.setCursor(11, 0);
  lcd.print(PID_TEMP);
  lcd.setCursor(15, 0);
  lcd.write(10);
  lcd.setCursor(0, 1);
  lcd.print("CUR: ");
  lcd.setCursor(4, 1);
  lcd.print(BAT_CURRENT);
  lcd.setCursor(8, 1);
  lcd.print("A");
  lcd.setCursor(11, 1);
  lcd.write(11);
  Serial.print(" | SOLAR | ");
  Serial.print("VOLTAGE: ");
  Serial.print(SOL_VOLTAGE);
  Serial.print(" CURRENT: ");
  Serial.print(BAT_CURRENT);
  Serial.print(" BATTERY TEMP.: ");
  Serial.print(PID_TEMP);
  Serial.print(" °C ");
  // Serial.print(SOL_VOL);
}
void BATTERY_INFO()
{
  lcd.createChar(9, TEMP);
  lcd.createChar(10, CELSIUS);
  lcd.createChar(12, BATTERY);
  lcd.home();
  BAT_VOL = analogRead(BVOL);
  BAT_VOLTAGE = BAT_VOL * (4.0 / 4096);
  BAT_CURRENT = (ACS.mA_DC() / 1000);
  RAW_TEMP = analogRead(LM);           // Read LM ADC
  PID_TEMP = ((RAW_TEMP * 1.22) / 10); // Convert ADC value to equivalent voltage and divide since LM35 gives output of 10mv/°C*/
  lcd.setCursor(0, 0);
  lcd.print("VOL:");
  lcd.setCursor(4, 0);
  lcd.print(BAT_VOLTAGE);
  lcd.setCursor(8, 0);
  lcd.print("V");
  lcd.setCursor(10, 0);
  lcd.write(9);
  lcd.setCursor(11, 0);
  lcd.print(PID_TEMP);
  lcd.setCursor(15, 0);
  lcd.write(10);
  lcd.setCursor(0, 1);
  lcd.print("CUR: ");
  lcd.setCursor(4, 1);
  lcd.print(BAT_CURRENT);
  lcd.setCursor(8, 1);
  lcd.print("A");
  lcd.setCursor(11, 1);
  lcd.write(12);
  Serial.print(" | BATTERY | ");
  Serial.print("VOLTAGE: ");
  Serial.print(BAT_VOLTAGE);
  Serial.print(" CURRENT: ");
  Serial.print(BAT_CURRENT);
  Serial.print(" BATTERY TEMP.: ");
  Serial.print(PID_TEMP);
  Serial.println(" °C  |");
}
String SendHTML(float SOL_VOLTAGE, float BAT_CURRENT, float PID_TEMP, float BAT_VOLTAGE)
{
  String ptr = "<!DOCTYPE html> <html>\n";
  ptr += "<head><meta name=\"viewport\" content=\"width=device-width, initial-scale=1.0, user-scalable=no\">\n";
  ptr += "<meta content=\"Advait Thale\" name=\"author\"><meta content=\"2\" http-equiv=\"refresh\">\n";
  ptr += "<title>MPPT Monitor</title>\n";
  ptr += "<style>html { font-family: Helvetica; display: inline-block; margin: 0px auto; text-align: center;}\n";
  ptr += "body{margin-top: 50px;} h1 {color: #444444;margin: 50px auto 30px;}\n";
  ptr += "p {font-size: 24px;color: #444444;margin-bottom: 10px;}\n";
  ptr += "footer {text-align: center;text-decoration: none;position: fixed;left: 0;bottom: 0;width: 100%;height: 3%;padding: 2px;background-color: #00004d;color: #f2f2f2;}\n";
  ptr += "</style>\n";
  ptr += "</head>\n";
  ptr += "<body>\n";
  ptr += "<div id=\"webpage\">\n";
  ptr += "<h1>MPPT MASTER DASHBOARD</h1>\n";
  if (PID_TEMP >= 50)
  {
    ptr += "<p>TEMP. OVERLOAD<svg width=\"170\" height=\"15\"><rect x=\"15\" y=\"5\" rx=\"7\" ry=\"7\" width=\"20\" height=\"10\" style=\"fill: #e60000\"/></svg> </p>";
  }
  else if (PID_TEMP > 25 && PID_TEMP < 50)
  {
    ptr += "<p>TEMP. OVERLOAD<svg width=\"170\" height=\"15\"><rect x=\"15\" y=\"5\" rx=\"7\" ry=\"7\" width=\"20\" height=\"10\" style=\"fill: #ff8800\"/></svg> </p>";
  }
  else
  {
    ptr += "<p>TEMP. OVERLOAD<svg width=\"170\" height=\"15\"><rect x=\"15\" y=\"5\" rx=\"7\" ry=\"7\" width=\"20\" height=\"10\" style=\"fill: #009933\"/></svg> </p>";
  }

  ptr += "<p> BATTERY\n </p>";
  ptr += "<p> Voltage: ";
  ptr += (float)BAT_VOLTAGE;
  ptr += "</p>";
  ptr += "<p> Current: ";
  ptr += (float)BAT_CURRENT;
  ptr += "</p>";
  ptr += "<p> Temp.: ";
  ptr += (float)PID_TEMP;
  ptr += "</p>";
  ptr += "<p> SOLAR\n </p>";
  ptr += "<p> Voltage: ";
  ptr += (float)SOL_VOLTAGE;
  ptr += "</p>";
  ptr += "</div>\n";
  ptr += "<footer>MPPT MASTER DASHBOARD -> @Author: Advait Thale</footer>";
  ptr += "</body>\n";
  ptr += "</html>\n";
  return ptr;
}
// void IR_MOSFET_Control()
// {
//   if (IrReceiver.decode())
//   {
//     switch (IrReceiver.decodedIRData.command)
//     {
//     case 0x84:
//       digitalWrite(MOSFET_1, !digitalRead(MOSFET_1));
//       Serial.println("<OUTPUT 1 Engaged>");
//       break;

//     case 0xD9:
//       digitalWrite(MOSFET_2, !digitalRead(MOSFET_2));
//       Serial.println("<OUTPUT 2 Engaged>");
//       break;

//     case 0x89:
//       digitalWrite(BUZZ, !digitalRead(BUZZ));
//       Serial.println("ALARM ON");
//       break;

//     default:
//       Serial.println(IrReceiver.decodedIRData.command, HEX);
//       //        Serial.println("Default");
//     }
//     IrReceiver.resume(); // Receive the Next Value
//   }
// }

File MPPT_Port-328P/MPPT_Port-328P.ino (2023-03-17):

/*
  Author: Advait Thale

  *************************************************************************************************
                                     MPPT_PORT-328P
  *************************************************************************************************

  This test code is an overview of how MPPT works on the port of ATMega328P.
  It is equipped with 20*4 Character LCD (for device & energy status), Function
  Buttons, ATMega328P Microcontroller, Solar Inlet, 30A FUSE, Sleep Mode,
  2 x PT-100(for Indoor & Outdoor Temp.), RS-232 Interface(at 9600),Program
  Serial(at 115200), Internal DIP Switches (for system configuration), Relay
  driven Outputs(for automation purpose), I/O for interfacing external
  sensors and automation purpose.
  The live status is displayed on LCD as well as the data log can be viewed via
  both RS-232 (DB9) or USB A Serial ports. Refer README.md and attached datasheets
  for furthur details on MPPT.

  **************************************************************************************************
                                           328P-U PINOUT
  **************************************************************************************************

                              BUZZ |*| D13         D12 |*| C.START
                               3V3 |*|             D11 |*|
                               GND |*| AREF        D10 |*|
                               CUR |*| A0           D9 |*| RELAY
                                   |*| A1           D8 |*| RELAY
                         PT-100(I) |*| A2           D7 |*|
                         PT-100(O) |*| A3           D6 |*|  -
                               SDA |*| A4           D5 |*| CURRENT
                               SCL |*| A5           D4 |*| AMB TEMP / HUM
                                -  |*| A6           D3 |*|
                                -  |*| A7           D2 |*|
                                   |*| 5V          GND |*|
                                   |*| RST         RST |*|  -
                                   |*| GND         RX0 |*|  TX
                                -  |*| VIN         TX0 |*|  RX

  ***************************************************************************************************


  # Standardised System Variables

  BYTA      Alarm                        ON/OFF
  BYTB      Battery                      Percentage
  BYTO      Outdoor Temperature          C(Degree Celcius)
  BYTI      Current (AC/DC) upto 20A      A(Ampere)
  BYTT      Indoor Temperature           C(Degree Celcius)
  BYTL      Load Power                   W(Watts)
  BYTP      Power                        W(Watts)
  BYTS      Generated(Solar) Power       W(Watts)
  BYTH      Humidity                     Percentage

*/

// #include <math.h>   // Math Functions
// #include <ACS712.h> // ACS712 Functions
#include <DHT.h>  // Ambient Temperature/Humidity Functions
#include <Wire.h> // For communication with I2C devices
#include <LiquidCrystal_I2C.h>
#include <IRremote.h>

// #define CUR 2
// #define DHTPIN 5
// #define BUZZ 4
// #define LED 2
#define dt 2000

long DUR;
const byte IR_RECEIVE_PIN = 2; // IR receiver
float BYTA, BYTB, BYTI, BYTO, BYTT, BYTL, BYTP, BYTS, BYTH, THLD1, THLD2;
byte charge[13] = {0x04, 0x0C, 0x1C, 0x1F, 0x1F, 0x07, 0x06, 0x04};
byte error[14] = {0x00, 0x0E, 0x13, 0x17, 0x1D, 0x19, 0x0E, 0x00};
byte restore[15] = {0x00, 0x0D, 0x13, 0x17, 0x10, 0x10, 0x0E, 0x00};
int ILCD = 11; // LCD Pin
int GLED = 12; // LED Pin
int BUZZ = 4;  // BUZZER Pin

// dht DHT;
// ACS712 sensor(ACS712_05B, 2);
LiquidCrystal_I2C lcd(0x27, 20, 4);

void setup()
{
  Serial.begin(115200); // Program Port Serial Baud
  Serial.println("<--- MPPT Rev_8.07 --->");
  IrReceiver.begin(IR_RECEIVE_PIN, ENABLE_LED_FEEDBACK);
  pinMode(ILCD, OUTPUT);
  pinMode(GLED, OUTPUT);
  //  pinMode(CUR, INPUT);          // ADC Pin for ACS712
  pinMode(BUZZ, OUTPUT); // Buzzer Pin for Beeps
                         //  pinMode(DHTPIN, INPUT);       // DHT11 Pin as Input
  //  Serial1.begin(9600);          // Compensated RS-232 Port Baud 9600
  //  attachInterrupt(ISR, RISING, 0); // Attach Interrupt
  //  lcd.init();                   // LCD Initialise
  //  lcd.backlight();              // LCD Backlight ON
  //  initial();                    // Device Start Configuration
  //  Wire.begin();                 // Initiate wire lib. and I2C
  //  Wire.beginTransmission(0x68); // Start transmission to 0x68(MPU)
  //  Wire.write(0x6B);             // Power Management Register (PWR_MGMT_1)
  //  Wire.write(0);                // Wake up IMU
  //  Wire.endTransmission(true);   // End transmission to I2C slave
  digitalWrite(ILCD, LOW);
  digitalWrite(GLED, LOW);
  digitalWrite(BUZZ, LOW);
}
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

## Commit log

2023-01-21 Bugs & Fixes (#2)
    [MPPT_Port-328P.ino]
2023-01-23 Bugs & Fixes (#3)
    [MPPT_Port-Xtensa.ino]
2023-01-29 Bugs & Fixes (#4)
    [MPPT_Port-Xtensa.ino]
2023-02-05 Bugs & Fixes (#5)
    [MPPT_Port-Xtensa.ino]
2023-02-05 Bugs & Fixes (#6)
    [MPPT_Port-Xtensa.ino]
2023-02-11 PCB (#3)
    [MPPT PCB rev1.kicad_pcb, MPPT PCB rev1.kicad_sch]
2023-02-12 Bugs & Fixes (#7)
    [MPPT_Port-Xtensa.ino]
2023-02-15 Bugs & Fixes (#8)
    [MPPT_Port-328P.ino]
2023-02-21 Bugs & Fixes (#10)
    [irrec.ino]
2023-02-22 Bugs & Fixes (#11)
    [IR_Receiver.ino]
2023-02-24 Bugs & Fixes (#12)
    [MPPT_Port-328P.ino]
2023-02-28 PCB (#4)
    [MPPT PCB rev1.kicad_pcb, MPPT PCB rev1.kicad_sch]
2023-03-01 PCB (#5)
2023-03-02 PCB (#6)
2023-03-03 PCB (#7)
2023-03-08 PCB (#8)
2023-03-13 PCB (#9)
2023-03-13 Bugs & Fixes (#13)
    [IR_Switch_Case.ino]
2023-03-14 Bugs & Fixes (#14)
    [IR_Switch_Case.ino]
2023-03-15 Bugs & Fixes (#15)
    [IR_Switch_Case.ino]
2023-03-15 PCB (#10)
2023-03-16 PCB (#11)
    [MPPT.kicad_pcb, MPPT.kicad_sch]
2023-03-16 PCB (#12)
2023-03-16 PCB (#13)
2023-03-16 PCB (#14)
2023-03-17 PCB (#15)
2023-03-17 PCB (#16)
2023-03-17 PCB (#17)
2023-03-17 PCB (#18)
2023-03-17 Config (#21)
    [Bill of Material.xlsx]
2023-03-18 PCB (#19)
2023-03-18 PCB (#20)
2023-03-20 PCB (#21)
2023-03-20 PCB (#22)
2023-03-21 PCB (#23)
2023-03-21 PCB (#24)
2023-03-22 PCB (#25)
2023-03-23 PCB (#26)
2023-03-23 PCB (#27)
2023-03-23 PCB (#28)
    Inverter
2023-03-24 PCB (#29)
2023-03-26 PCB (#30)
2023-03-27 PCB (#31)
2023-03-28 PCB (#32)
2023-03-28 PCB (#33)
2023-03-29 PCB (#34)
2023-03-30 PCB (#35)
2023-03-30 PCB (#36)
2023-03-31 PCB (#37)
2023-03-31 PCB (#38)
2023-03-31 PCB (#39)
2023-03-31 PCB (#40)
2023-03-31 PCB (#41)
2023-03-31 PCB (#42)
2023-04-01 PCB (#43)
2023-04-02 PCB (#44)
2023-04-02 PCB (#45)
2023-04-02 PCB (#46)
2023-04-03 PCB (#47)
2023-04-04 PCB (#48)
2023-04-05 PCB (#49)
2023-04-06 PCB (#50)
2023-04-07 PCB (#51)
2023-04-07 PCB (#52)
2023-04-08 PCB (#53)
2023-04-09 PCB (#54)
2023-04-12 PCB (#55)
2023-04-12 PCB (#56)
2023-04-13 PCB (#57)
2023-04-14 PCB (#58)
2023-04-14 PCB (#59)
2023-04-15 PCB (#60)
2023-04-15 PCB (#61)
2023-04-16 PCB (#62)
2023-04-17 PCB (#63)
2023-04-18 PCB (#64)
2023-04-19 PCB (#65)
2023-04-19 PCB (#66)
2023-04-20 PCB (#67)
2023-04-21 PCB (#68)
2023-04-21 PCB (#69)
2023-04-21 PCB (#70)
2023-04-21 PCB (#71)
2023-04-21 PCB (#72)
2023-04-21 PCB (#73)
2023-04-22 PCB (#74)
2023-04-22 PCB (#75)
2023-04-22 PCB (#76)
2023-04-22 PCB (#77)
2023-04-22 PCB (#78)
2023-04-22 PCB (#79)
2023-04-23 PCB (#80)
2023-04-23 PCB (#81)
2023-04-23 PCB (#82)
2023-04-23 PCB (#83)
2023-04-23 PCB (#84)
2023-04-24 PCB (#85)
2023-04-24 PCB (#86)
2023-04-25 PCB (#87)
2023-04-25 PCB (#88)
2023-04-25 PCB (#89)
2023-04-25 PCB (#90)
2023-04-26 PCB (#91)
2023-04-26 PCB (#92)
2023-05-01 PCB (#93)
2023-05-01 Bugs & Fixes (#16)
    [MPPT_Port-Xtensa.ino]
2023-05-07 PCB (#94)
2023-05-07 Bugs & Fixes (#17)
    [IR_Switch_Case.ino]
2023-05-08 PCB (#95)
2023-05-13 Bugs & Fixes (#18)
    [IMU_connect.ino]
2023-05-13 Bugs & Fixes (#20)
    [main.cpp]
2023-05-13 Bugs & Fixes (#21)
    [vol.ino]
2023-05-14 Bugs & Fixes (#24)
    [main.cpp]
2023-05-16 Bugs & Fixes (#27)
    [main.cpp]
2023-05-16 PCB (#96)
2023-05-16 Bugs & Fixes (#28)
    [main.cpp]
2023-05-17 Bugs & Fixes (#29)
    [main.cpp]
2023-05-18 Bugs & Fixes (#31)
    [main.cpp]
2023-05-18 PCB (#97)
2023-05-19 Bugs & Fixes (#32)
    [main.cpp]
2023-05-25 Bugs & Fixes (#33)
    [main.cpp]
2023-05-26 Bugs & Fixes (#34)
    [main.cpp]
2023-07-10 Bugs & Fixes (#35)
    [OLED_CALC.ino]
2023-11-27 Bugs & Fixes (#36)
    [vol.ino]
2023-11-27 PCB (#98)
    [MPPT.kicad_pcb, MPPT.kicad_sch]
